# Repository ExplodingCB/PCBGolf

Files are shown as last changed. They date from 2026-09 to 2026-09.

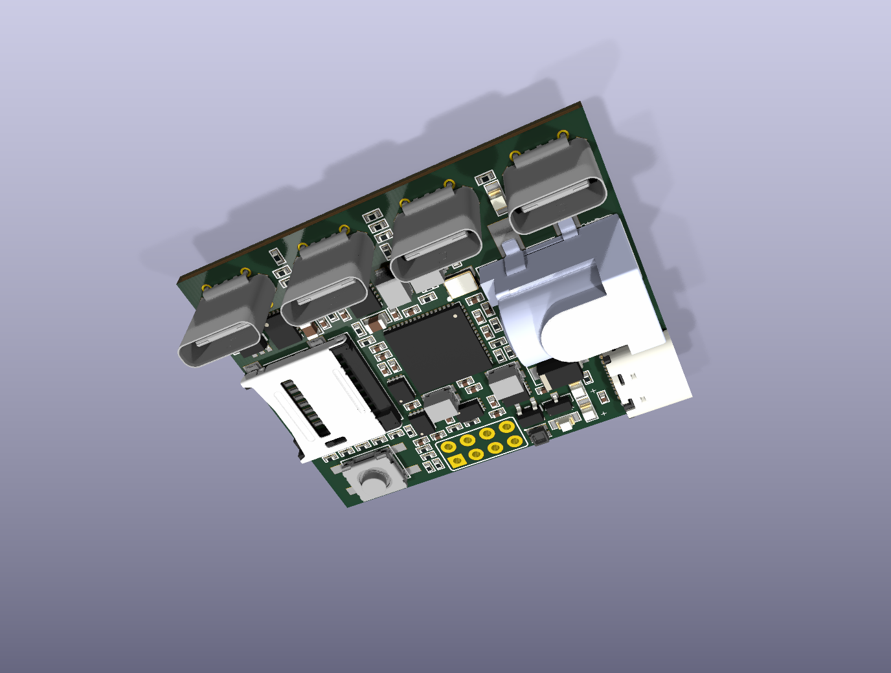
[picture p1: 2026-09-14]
reports/current-placement.png

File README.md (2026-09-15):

> **Engineering handoff — incomplete and not submitted.** Start with [HANDOFF.md](HANDOFF.md). The latest 45 × 37 mm, four-layer BGA100 checkpoint is in [work-in-progress/](work-in-progress/README.md), including an assembly STEP. It has **184 remaining pad-group connections and zero physical DRC errors**. Work stopped at the owner's request; all subagents and routing jobs are stopped. The root project is an earlier placement baseline.

<div align="center">
<h1>PCBGolf Challenge</h1>
<h3>How small can you make this PCBA?</h3>
<h3>
  <a href="https://comma.ai/leaderboard#pcbgolf_challenge">Leaderboard</a>
  <span> · </span>
  <a href="https://comma.ai/jobs">comma.ai/jobs</a>
  <span> · </span>
  <a href="https://discord.comma.ai">Discord</a>
  <span> · </span>
  <a href="https://x.com/comma_ai">X</a>
</h3>
</div>

## The Board

The schematic is loosely based on [our panda jungle v2](https://www.comma.ai/shop/panda-jungle), a development and debugging board for comma devices and pandas. This version includes:

* 12V DC input with onboard 5V and 3.3V supplies
* Four [OBD-C](https://github.com/commaai/hardware/blob/master/harness/OBD-C.sch.pdf) device ports with individually controlled power and current monitoring
* Four CAN transceivers and ignition simulation circuitry
* A USB hub and USB-C host connection
* An STM32H725 microcontroller and microSD card slot
* A push button and status LEDs

Explore in your browser with KiCanvas: [PCB layout](https://kicanvas.org/?github=https%3A%2F%2Fgithub.com%2Fcommaai%2FPCBGolf%2Fblob%2Fmaster%2Fpcbgolf.kicad_pcb).

Schematics: [Power](https://kicanvas.org/?github=https%3A%2F%2Fgithub.com%2Fcommaai%2FPCBGolf%2Fblob%2Fmaster%2Fpcbgolf.kicad_sch) · [Microcontroller](https://kicanvas.org/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) · [USB & microSD](https://kicanvas.org/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) · [CAN](https://kicanvas.org/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) · [OBD-C ports](https://kicanvas.org/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)

PCBgolf — A little board goes a long way. $1,000 prize.

## The Challenge

Your goal is to make the most compact, efficient board that retains the same interfaces and functionality as the original design. The lowest score wins.

<p align="center">
  <picture>
    <source media="(prefers-color-scheme: dark)" srcset="./assets/score-dark.svg">
    Score = PCBA bounding box volume (mm³) + 50 × number of vias + 5,000 × number of copper layers.
  </picture>
</p>

### Rules

* The bare PCB must be fully manufacturable by JLCPCB.
* It must be possible to actually assemble the PCBA.
* The assembled product must work and be usable.
* Mating connectors must remain mechanically and electrically compatible.

### Prize

Lowest score on the [leaderboard](https://comma.ai/leaderboard#pcbgolf_challenge) by **October 12, 2026** wins **$1,000 cash**.

## Submission

Submit a `.zip` file containing your finalized KiCad project and a STEP file of the final assembly [here](https://forms.gle/US88Hg7UR6bBuW3BA).
Competitive scores will be posted on the [leaderboard](https://comma.ai/leaderboard#pcbgolf_challenge) after review. Multiple submissions allowed.

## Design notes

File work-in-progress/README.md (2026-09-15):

# PCBGolf engineering checkpoint

Updated September 14, 2026. **Incomplete, not fabrication-ready, and not submitted.** Work stopped at the owner's request. Start with [../HANDOFF.md](../HANDOFF.md) for exact artifact provenance, remaining blockers, toolchain and proposed continuation plan. All subagents and routing jobs are stopped.

## Current design

- 45 × 37 mm outline, four copper layers, 1.6 mm PCB thickness, 239 components.
- STM32H725VGH6 in an 8 × 8 mm TFBGA100 package, with corresponding schematic and GPIO changes.
- Project-local schematic symbols, footprints and 3D models are included. Open `pcbgolf.kicad_pro` here; the repository-root project is an earlier placement baseline.
- This snapshot is the last completed `via400` routing result: 2,715 track segments and 484 through vias. `pcbgolf.merge.json` records the initial merge only.
- `assembly.step` contains the board and all 236 populated component models. All 239 component placements were compared and exactly match this latest PCB; only routing changed after the STEP export. Final fabrication artifacts should be exported again.

## Known blockers

- `net-groups.json` reports **184 missing connections between connected pad groups across 113 nets**.
- `drc.json` contains **zero physical error records and zero hole-spacing warnings**. Unconnected items and other warnings still require completion and review.
- `connectivity-parity.json` passes all five schematic sheets: 239 components, zero component or pin/net differences.
- `usb-reference-audit.json` verifies all 17 ground return vias connect to both original inner layers. One small reference-copper gap remains flagged among 223 USB segments.
- CAN bus routing is partly integrated; connector and transceiver branches still require connections. The older isolated trial is documented separately in `../reports/can-routing-trial.md`.
- Power distribution, current capacity, final manufacturing checks and firmware/hardware validation remain unfinished. Some vias require filled and capped via-in-pad processing.

## Preserved work

Engineering scripts and reports are in `../scripts/` and `../reports/`. Reports describe their named candidates. `routing-source.*` and `routing-handoff/via400*` preserve the exact source, DSN, SES, hash and log for the latest output. `small-via-trial.*` is a separate older 190-open experiment with 130 reduced signal vias; do not replace the latest main board with it. Other experiments and installed toolchains remain local and are excluded from Git. **No six-layer conversion was implemented.**

Firmware source changes and the local build driver are in `../firmware/pcbgolf/`. Bootstub and application compiled and linked locally; neither was hardware-tested. No flashable binaries are included in this checkpoint.

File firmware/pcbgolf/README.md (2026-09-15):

# Experimental PCBGolf firmware

Source checkpoint for STM32H725VGH6 BGA100. Bootstub and application compiled and linked locally; hardware behavior and the complete pin map still require review and bench testing. This is not qualified firmware.

The build uses commaai/panda revision `78cf69904c332c599a297fcc2a09c08d10d429d5` and commaai/opendbc revision `057aee25b5eee7530f0b95b5b508c8c3247b0cd7`. Place the panda checkout at `tools/panda-firmware` and opendbc at `tools/panda-firmware/opendbc-src` relative to the repository root.

Apply `panda-changes.patch` inside the panda checkout, and copy `pcbgolf_bga100.h` to its `board/jungle/boards/` directory. The patch selects the PCBGolf board and overrides the historical TFBGA100 supply heuristic for the H725 SMPS and externally supplied USB rail.

`build.py` records the expected local Arm GNU 12.3.Rel1 Windows toolchain path and builds both images with `PCBGOLF_BGA100`. Generated outputs stay in the ignored `build/` directory. See `../../reports/firmware-build.json` for the saved compile result; it does not establish hardware correctness.

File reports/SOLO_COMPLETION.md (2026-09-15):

# Solo completion status — September 14, 2026

The owner requested a WIP push followed by continued work without subagents. All three agents are stopped. Continue toward a valid submission; do not restart size optimization or claim the active challenge goal is complete.

> **Superseded at the September 14, 2026 handoff.** The owner stopped work and requested a push for another engineer. Read `../HANDOFF.md`. Latest pushed board: 184 missing connections, zero physical DRC errors. No router or subagent is running. The following entries are chronological notes, not current instructions.

## Earlier checked checkpoint

`candidates/completion/finish.kicad_pcb`, copied into `work-in-progress/pcbgolf.kicad_pcb`: 45 × 37 mm, four layers, 239 components, 2,297 track segments and 417 vias. Native DRC: 220 opens, zero physical errors, zero hole-spacing warnings. No valid score or submission yet.

The original merged snapshot had 519 missing pad-group connections. Three USB ground-return vias had been reassigned to connector VBUS during zone integration. They were restored and set to free vias to preserve explicit net assignments. New ground fanout, local SMPS links, a front 3.3 V pour, and partial CAN routing are included.

The crystal is now at (3.6,15.35), C14 at (3.6,17.4), C17 at (1.0,16.3), and C19 at (4.05,24.3). The four clock links route on the bottom, with lengths 7.408/2.851 and 3.469/2.097 mm in the earlier validated clock result; the exact C17 move subsequently updated its short branch. `complete_clock.py` reproduces the layout and `repair_route_import.py` restores the checked clock geometry while removing only newly imported copper that violates native rules.

Five-sheet parity passed before these placement-only changes. Final parity must be rerun against the submission artifact. Earlier STEP bounds were 45 × 37 × 14.23 mm with no component AABB collisions; the WIP STEP is freshly exported after the clock move, but final geometry checks remain required.

USB's 17 return vias connect to both inner ground layers. Reference copper passed after removing 34 intruding CAN segments and adding inner track keepouts. One small reference gap reappeared after subsequent general routing; rerun the reference audit against the final board. `prepare_router.py` explicitly exports these keepouts because KiCad omitted track-only rule areas from its DSN.

## Router progress and next action

The current job uses `candidates/completion/flexible-bus.kicad_pcb`, with long CAN bus copper unlocked but the 32 checked connector escape vias preserved. Its input is `pofv.dsn`, its output will be `pofv.ses`, and its log is `pofv-router.log`. Native import must use the matching `pofv.preflight.json` source hash. The job is bounded to five minutes.

Filled/capped SMD vias require both `(attach on)` in via padstacks **and** `(control (via_at_smd on))` in the DSN structure. The earlier `finish` and `flexible` runs lacked the latter control; `pofv` enables both. Native DRC and a full filled/capped via map remain mandatory.

The local router JAR has only its existing normalization-loop limit reduced from 2,000 to 64, preventing long cleanup oscillations. `bound_router_cleanup.py` reproduces this isolated copy and records its hash; the official JAR is retained. No clearance or routing correctness checks are removed. Commands also use a five-minute job timeout, disabled optimizer, a 0.10 mm neck-width floor, 0.20 mm hole clearance and 0.30 mm copper-edge clearance.

## Remaining acceptance work

Complete all signals and power pad groups, repair any imported physical errors, recheck USB geometry/reference copper and clock preservation, verify power distribution and current capacity, final five-sheet parity, complete assembly and mating checks, final score and self-contained ZIP, then the official submission form. The form requires Google authentication; no submission has been made.

Experimental firmware compiled and linked. The new `audit_firmware_pinmap.py` checks 44 GPIO/ADC/CAN allocations against the schematic allocation and official ST pin data; all pass. `firmware/pcbgolf/pinmap.json` holds the results. Hardware operation and unimplemented peripheral behavior remain untested.

## Later solo routing handoff (21:30 local)
The 220-open WIP was pushed as commit 259a4a1. True via-at-SMD mode produced candidates/completion/pofv.kicad_pcb: 207 native opens, 2454 tracks, 447 vias, zero physical errors. connect_short_nets.py then connected 6 of 43 attempted local pairs; candidates/completion/short-links.kicad_pcb is the new router source (native preflight passes). Current running job: long-run.dsn -> long-run.ses, source hash in long-run.preflight.json, log long-router.log, ten passes and a twenty-minute timeout, started about21:27:40. Exec session5241. Do not run another concurrent router or reactivate agents. Import its SES into the matching short-links source, then run native DRC and uncapped connectivity.
connect_power_vias.py is written but NOT YET RUN. Apply it to the best completed general-routing result. It proposes legal0.4/0.2mm filled/capped vias on disconnected power/GND pad groups, refills, and prunes additions whose removal does not worsen pad-group count. Native DRC, final power capacity and USB reference review remain mandatory. The final four-layer board is still incomplete; do not claim ready or submit.

## Dense-routing constraints found (21:42 local)
The long job completed two passes with the same191 internal unrouted count (no improvement on pass2); it is due to time out around21:47:40. Do not repeat unchanged settings. DSN Default class had a use_via restriction to0.45/0.20mm even though the0.40/0.20mm padstack already existed. prepare_router.py now selects the0.40/0.20mm stack when filled-via mode is enabled; that change is NOT in the currently running long-run.dsn. Verified generated DSN has both control/via_at_smd on and class/use_via400. For the next completion run, increase --router.scoring.unrouted_net_penalty=100000000 (default5000000) so false router-only DRC counts cannot outweigh completing connections. Do not disable native checks or change manufacturing rules. The router internal score is higher-is-better and includes a1000000 penalty for each router DRC record; native PCB currently has no physical errors despite hundreds of router-only reports.
If a six-layer power-distribution change eventually becomes necessary, official JLCPCB stackup page https://jlcpcb.com/impedance lists JLC06161H-3313 with the same0.09940mm outer prepreg as current4L;0.55mm cores,0.1088mm central prepreg,0.0152mm inner copper. This is only research, no6L conversion has been applied. First finish the0.4mm-via path and power connections on4L.

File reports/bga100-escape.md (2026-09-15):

# BGA100 through-via escape experiment

The recommended isolated candidate is **`candidates/bga100-power-escape/pcbgolf.kicad_pcb`**. It uses the new power placement and reaches every connected MCU ball with **32 vias**, while preserving all 18 no-connects. Both the original `bga100-base` and the source `bga100-power-base` are unchanged. This is complete MCU fanout access, not completed end-to-end board routing.

## Measured result

| Item | Count |
|---|---:|
| Actual MCU balls | 100 |
| Connected balls / retained no-connects | 82 / 18 |
| First/second-row or critical supply access on B.Cu, without vias | 47 |
| Balls with through-via dogbones | 35 |
| Added through vias | **32** |
| Shared same-net vias | 3 |
| Total balls with access | **82 / 82** |
| Balls still without access | **0** |
| Added track segments | 102 |

Native KiCad DRC reports **zero physical violations**, including warning-level hole-spacing checks, with no DRC exclusions or rule changes. The 27 dangling-via and 47 dangling-track warnings identify intentionally unfinished signal routes. Five GND vias connect all six ground balls into filled In1 GND copper, checked using native filled-zone geometry. Five-sheet logical parity passes with zero component or pin-net differences across all 239 parts. Unconnected records are capped at 499, so this number is a lower bound. Remaining silk/text warnings and two existing footprint-library mismatches need final cleanup.

Every via is a **0.45 mm copper / 0.20 mm through drill**, reached by a **0.12 mm B.Cu track** at ±0.4 mm x/y offsets from a ball. Candidates screen copper and drills on every layer, including opposite-side SMD pads, before native DRC. No via-in-pad, microvia, blind via or clearance waiver is assumed. The 0.45 mm component-PTH-to-component-PTH and 0.20 mm generic drilled-hole separation rules remain in the copied project.

## Placement and via reduction

| Experiment | MCU center | Accessible balls | Vias | Physical DRC |
|---|---|---:|---:|---|
| Original pose, one direct row | 15.6, 19.9 | 66/82 | 36 | Passed |
| Shifted pose, one direct row | 10.5, 19.9 | 82/82 | 50 | Passed |
| Shifted pose, two direct rows | 10.5, 19.9 | 82/82 | 32 | Passed |
| New power placement, two direct rows | 10.5, 19.9 | 82/82 | **32** | **Passed** |

At the original pose, opposite-side U7, C35, U4, C33 and C30 blocked the dogbone grid. Moving the MCU left resolved all blocked sites without moving the hub or transceiver. X=9.5 and x=11.5 at y=19.9 also passed complete one-row escapes; x=10.5 was chosen for the power placement. The second direct row removed **18 vias**, saving **900 challenge score points** relative to the first complete 50-via fanout, before any later routing changes.

Final MCU pose is **x=10.5, y=19.9 mm, B.Cu, 0°**. Balls occupy x=6.9–14.1 and y=16.3–23.5 mm. The original 10 × 10 mm BGA courtyard is retained. Bottom direct-access stubs reach x=6.1/14.9 and y=15.5/24.3; subsequent placement must include trace copper and clearance beyond these centerlines.

Shared vias are C1/D1 GND at (6.5,21.5), D6/E5 +3V3 at (10.5,20.7), and G6/F7 VDDLDO at (11.3,19.1). C2/VBAT exits through the gap above C1, preserving the shared ground-via cell beside the switching escape.

## Reserved MCU supply access

- D2/VLXSMPS: (7.7,21.1) → (7.3,20.7) → (6.1,20.7), B.Cu.
- E2/VFBSMPS: (7.7,20.3) → (7.3,19.9) → (6.1,19.9), B.Cu.
- E1/VDDSMPS reaches (6.1,20.3) on B.Cu.

These keep switching and feedback access direct. The new power placement brings L4's switching pad to (5.07,20.7); its bulk/bypass parts are nearby. Actual supply interconnects remain for the power-routing stage. The 0.12 mm stubs demonstrate geometric access and are not final current/inductance sizing. In2 stays +12V; MCU +3V3, VDDLDO and VDDA require correctly named local supply copper and decoupling. No fanout is connected to the wrong plane. Supply requirements are in `reports/mcu-bga100-supply-check.md`. USB fanout access has not been certified for differential impedance or skew.

## Reproduce or refresh

```powershell
tools/kicad/bin/python.exe scripts/escape_bga100.py --source candidates/bga100-power-base --output candidates/bga100-power-escape --direct-rings 2
```

For a copy that already contains a prior escape and its matching `escape-report.json`, remove only the listed old escape UUIDs in another output copy before rebuilding:

```powershell
tools/kicad/bin/python.exe scripts/escape_bga100.py --source candidates/your-placement-copy --output candidates/your-refreshed-escape --refresh-known-escape --direct-rings 2
```

The refreshed input must contain only the known escape tracks/vias; other newly routed copper is rejected until that use case is explicitly supported. This prevents silently omitting existing routing obstacles. The script saves its report, native DRC JSON and merged connectivity report beside its output board.

## Assembly spacing

The BGA courtyard was kept at its official size. KiCad specifies a 1.0 mm BGA courtyard allowance. JLC's current recommended minimum component spacing is 1.0 mm between a BGA and chip passives, and 1.5 mm to QFN/QFP. Reducing the courtyard does not establish assembly-process acceptance. The native copper/hole checks above are separate from the final assembly and mechanical review. [KiCad KLC F5.3](https://klc.kicad.org/footprint/f5/f5.3.html), [JLC SMD spacing](https://jlcpcb.com/help/article/minimum-spacing-for-smd-components)

## USB integration reservation

`candidates/bga100-power-escape-usb-reserved` preserves the generic fanout reference above and replaces only its three STM_D_P/N access tracks. It adds the USB routing agent's two 0.40/0.20 mm vias: P at U3.D9 (13.3,21.1), and N at (13.7,20.7) with a 0.11 mm B.Cu diagonal from D10 (14.1,21.1). This snapshot has **34 total vias and 100 track segments**, zero physical DRC violations and passing five-sheet parity. Its `usb-reservation.json` records every removed/added UUID for integration.

The P via is **via-in-pad and requires filled, copper-capped POFV**. The reserved USB path is not yet a completed differential route; the USB agent will retain these vias and add its matched continuation. Do not duplicate them when combining candidates. The original 32-via generic fanout remains unchanged for evidence.

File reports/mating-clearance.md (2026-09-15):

# Mating connector clearance

## Finding

The first 45×37 mm layout's OBD-C socket row had 11.3–11.7 mm spacing along the plug's wide axis. **This does not accommodate every compliant full-featured USB-C plug.** USB-IF Table B-1 specifies maximum overmold width **12.35 mm** and height **6.5 mm**. [Official compliance document, printed page49](https://www.usb.org/sites/default/files/USB%20Type-C_Compliance%20Document_Rev_2_1b_June_2021.pdf).

Comma describes OBD-C as a fully connected USB-C 3.1 Gen2 or 3.2 Gen2 cable. Its public hardware documentation does not provide an exact proprietary overmold drawing. [Comma hardware harness documentation](https://github.com/commaai/hardware/blob/master/harness/README.md).

## Corrected candidate

`reports/placement-45x37-mating.json` rotates all four OBD-C sockets by90° and places them at X=3.25,10.75,18.25,25.75 mm, Y=4.75 mm. Their **narrow-axis pitch is7.5 mm**. This provides1.0 mm between maximum-width USB-IF compliant overmolds in that direction.

The mechanical check deliberately enlarges the USB-IF cross section to **12.5×7.0 mm**, giving **0.5 mm interplug separation**. The rightmost envelope ends atX=29.25 mm; the actual tall barrel-jack model begins atX=29.6 mm, giving0.35 mm clearance. The cable bodies may overhang short components because the plug overmolds begin above the vertical USB sockets, roughly8.8 mm above the board. The audit starts them at8.6 mm to include an extra0.2 mm vertically.

J4 moves to the clear upper-right corner at(38,4), and the bottom MCU shifts toY=20.7 mm so all connector drill envelopes clear it. The board remains45×37 mm. The PNG shows elevated cable envelopes as dashed yellow rectangles. They are usability checks and are excluded from PCBA volume scoring.

## Scope

These calculations check simultaneous insertion geometry using conservative straight-plug envelopes and nominal component models. They do not establish insertion force, latch retention, cable bend space, or compatibility with unusually oversized/right-angle custom cable housings. A representative physical mating test remains part of final validation. The optional DNP J4 header requires its own mating-body model if populated.

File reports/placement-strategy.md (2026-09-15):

# Compact placement strategy and measured candidates

## Current recommendation

Use `reports/placement-45x42-courtyards.json` as the next native KiCad placement. It places **239 footprints on a 45 × 42 mm PCB** and preserves the actual source and corrected-library assembly courtyards. The plan includes every remaining electrically required reference after the separately verified removal of four unconnected mounting holes and redundant R5/R6 divider resistors. JSON contains native footprint origins, rotations, and sides, plus conservative occupied bounds.

This is a placement candidate, not a completed submission. Routing, current capacity, USB impedance, electrical checks, connector insertion clearance, and final assembly checks remain required.

## Measured bounds and scoring

The native STEP exports of `compact-v1-4l` and `compact-v2-4l` measure **45 × 42 × 15.005 mm**, giving **28,359.45 mm³** of assembly volume. These measurements come from the actual exported assembly using OpenCascade, not a sum of nominal package heights. J1 sets the top height; the bottom CAN chokes set the lower extent. The exported assemblies contain 236 populated component models plus the PCB; C6, C10, and J4 are DNP in the corrected project.

At this measured size:

- Two-layer score before vias: 38,359.45.
- Four-layer score before vias: 48,359.45.
- Every 100 vias adds 5,000.
- Shrinking board width by 1 mm at fixed height saves about 630 score.
- Shrinking board height by 1 mm saves about 675 score.
- Lowering the assembly by 1 mm saves 1,890 score.
- A two-layer design may use **200 additional vias** before it loses its 10,000-point copper-layer advantage, assuming the same physical volume.

The original pad/body rectangle sum was 2,229.61 mm². Its optimistic two-sided area floor was 1,114.81 mm², before routing, courtyards, connector insertion, thermal clearance, and packing waste. Correcting oversized SOIC-8 footprints to the actual SOT-553 part and removing the approved unnecessary items lowers physical occupied area, but J1's corrected 17 mm pad span increases it. V3's actual courtyard/body envelope sum is 2,432.47 mm², about 64% of the available two-sided 3,780 mm² surface.

## Fixed interface arrangement

Coordinates are millimetres. Rotations follow KiCad; bottom footprints are flipped top-to-bottom before applying the listed angle.

| Reference | Side | Footprint origin | Angle | Access |
|---|---|---:|---:|---|
| U3 | Top | (13.0, 22.5) | 180° | Rotation puts oscillator pins on the free right side and SD pins toward the left |
| J1 | Top | (39.5, 17.5) | 180° | Barrel opening faces the right board edge |
| J2 | Bottom | (1.31074, 15.125) | 90° | microSD opening faces the left edge |
| J3 | Top | (37.0, 33.15) | 0° | Host USB-C opening reaches the bottom edge |
| J4 | Top | (7.0, 38.5) | 0° | Original 2×4 CAN pad interface retained, DNP |
| J5–J8 | Top | X = 5.0, 16.7, 28.3, 40.0; Y = 4.0 | 0° | Vertical OBD-C insertion from above |
| SW1 | Top | (22.5, 38.5) | 0° | Finger access from above |
| U4 | Bottom | (22.0, 20.0) | 0° | Consider 270° in the next route-focused revision |

The OBD-C sockets are spaced 11.3–11.7 mm apart. Their bare sockets do not intersect. The **actual required cable overmold width** still needs verification; a plug wider than the socket spacing can invalidate this arrangement. Connector cable bodies are not included in the bare PCBA STEP score and cannot be ignored when checking usability.

## Placement constraints and verification

- Native KiCad STEP positions match the planner's mirrored-Y bottom-side transform, including the asymmetric microSD socket. The convention was checked on exported models rather than assumed.
- V2 has no pair of component 3D bounding boxes intersecting by more than 0.001 mm. Separated boxes prove separated solid models. PCB/lead insertion intersections are intentionally excluded from this test.
- Actual SOT-553 model size is 1.6 × 1.6 × 0.63 mm; the original pad-only estimate missed 0.15 mm of body extent per Y side. V3 preserves the full 2.36 × 2.20 mm library courtyard.
- Actual U3 courtyard is 23.3 × 23.3 mm, and the source-board 0402 courtyards are 1.946 × 0.966 mm. These are larger than the bare pad rectangles and were the cause of V2's courtyard errors. V3 incorporates them directly, with a further 0.05 mm gap. No courtyard was artificially reduced.
- J1 requires the corrected `PJ-002AH-SMT-TR` footprint. Its copper bounding box is local X [-1.25, 7.25], Y [-8.5, 8.5], and its full courtyard is [-5.3, -8.75, 10.2, 8.75]. The first bootstrap placement used the supplied incorrect footprint; V2 and V3 reserve the corrected physical pad span.
- The planner reserves through-hole and locating-hole obstacles on the opposite side as well as the component's own side.
- MCU crystal and bypass capacitors stay on the MCU side. Hub crystal and bypass capacitors stay on the hub side. Both switching regulators, their inductors, bootstrap/input/output capacitors, and feedback parts stay on the bottom side together. Placement priorities use actual relevant IC pin locations when available.

## USB routing priorities

`reports/usb-route-corridors.json` records the native pad endpoint coordinates for all six USB differential pairs. Route these before general signals and preserve pair spacing, a continuous reference plane, and equivalent via transitions. An unrestricted autorouter trial only establishes reachability; it does not establish USB signal integrity.

With U4 at (22,20), rotating it from 0° to **270°** reduces the sum of 12 USB-net Manhattan endpoint distances from **331.9 to 288.5 mm**, and turns its four OBD-C pair groups toward the top port row. The hub crystal and local bypass capacitors must be repacked if this change is adopted. For the present 0° orientation, route the four OBD-C pairs around the left/top hub side, the host pair toward the lower-right connector, and the MCU pair toward the lower-left MCU edge. Avoid crossing the microSD socket's routing escape with all four port pairs on the same layer.

## Files

- `scripts/placement_analysis.py`: source pad/model geometry inventory.
- `scripts/compact_placement.py`: first net-attracted bootstrap placement.
- `scripts/refined_placement.py`: same-side critical loops and enlarged J1.
- `scripts/courtyard_placement.py`: current courtyard-preserving placement.
- `scripts/render_placement.py`: PNG review renderer.
- `scripts/inspect_assembly.py`: actual STEP component names and bounds.
- `scripts/audit_assembly.py`: 3D separation and measured volume report.
- `scripts/usb_corridors.py`: exact USB endpoint coordinates and hub rotation comparison.
- `reports/compact-v2-4l-mechanical-audit.json`: native V2 model separation and dimensions.

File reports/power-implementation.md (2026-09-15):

# Power implementation and handoff

## Concrete candidate

Use `candidates/power-base/power-critical.kicad_pcb`, with its matching `.kicad_pro` and `.kicad_dru`. The placement-only base is `candidates/power-base/pcbgolf.kicad_pcb`; `reports/placement-power-clusters.json` records all239 positions. This is an isolated45×37×1.6mm four-layer candidate. Root and the USB agent's active board were not overwritten.

The board contains58 power/thermal vias and143 track segments. All201 copper items are locked. Sixteen vias are0.20mm holes/0.40mm copper in eFuse exposed pads and require epoxy-filled, copper-capped POFV. Their closest component-hole edge gap is2.019mm, exceeding the conservative0.45mm requirement. The exact UUID/coordinate map is in `candidates/power-base/power-audit.json`. Paid four-layer POFV is documented in `reports/pofv-four-layer.md`.

Native KiCad10.0.6 DRC reports zero error-severity violations,285 warnings, and499 reported unconnected items. The unconnected list reaches the report limit; this is an incomplete board. Combined five-sheet logical parity passes for all239 parts with zero component or pin/net differences. Reports: `critical-drc.json`, `connectivity.json` in the candidate directory.

## Electrically connected power paths

The audit unions actual filled polygons with tracks/pads on every layer, including polygon holes, then connects layers only through actual vias/PTHs. It confirms:

- Both J1 power lands, D1 and every Q1 drain pad share one copper group.
- Q1 source pads, all20 eFuse VIN pads, U2 VIN, C3 and C5 share the+12V group through In2.Cu.
- Each eFuse's five output pads connect to all four corresponding connector VBUS contacts. The four output nets remain separate. LED-series resistors R74–R77 still need their low-current branches.
- U1 SW, L1 input and C4 switch side connect together. U3 VLXSMPS→L4→C25 has a2.681mm,0.30mm main route and1.286mm,0.20mm snubber branch.

Local output pours occupy both outer layers and leave the USB center/right exit reservations. The supply transition banks use parallel vias; short pin escapes are0.20–0.80mm wide. These facts establish electrical continuity, not an ampacity rating. Filled-copper neck widths, via current sharing and return-path temperature still need calculation and hardware validation after USB/general routing.

## Limits that must remain explicit

J1 is a5A total input jack. Each TPS25944A has a nominal3.18A trip setting with28kΩ ILIM; simultaneous channel maxima exceed the jack rating. AP62300 is a3A IC, but both selected3.3µH inductors have1.8A saturation/2A thermal ratings. Do not rate either assembled rail3A from the IC name alone. The existing+3V3 rail is cascaded from+5V, so combined regulator loading matters.

The preliminary1oz/10°C screen uses3.5mm drawn input trunk width and5.5mm channel trunk width for the TI twice-full-load copper recommendation. The current pours have not demonstrated these widths at every bottleneck. No thermal or load rating is asserted.

## Required next changes

1. Move eFuse input10µF/100nF capacitors near each VIN bank. C50–C52 and several small bypasses are remote. Connector shield holes and the LQFP courtyard block the convenient lower row; the BGA100 branch frees that area. Proposed bypass repack script currently refuses this collision and has not changed the saved placement.
2. Repack U1/U2 dividers and bootstrap capacitors beside the respective pins. R3/R4 are13.65/10.31mm from U1 FB; R9/R10 are6.06/8.40mm from U2 FB. These require placement correction. The5.75mm bootstrap paths are provisional and should shorten with the move. U2SW→L2 and U1VIN→C1 remain open.
3. Complete MCU direct-SMPS input/output loop. L4 output→VFBSMPS/VCAP/VDDLDO and bulk C21/C15 remain unconnected; the bulk caps are26.14/28.04mm away and must move. U3VDDSMPS→C23 also needs a short path. L3 is the analog ferrite, not the SMPS inductor.
4. Add eFuse/MCU/regulator ground returns and general GND fanout with the parent's ground script after final placement. Exposed-pad thermal vias are already present; avoid duplicates. No ground copper ampacity claim is made.
5. Merge USB geometry, refill all zones, repeat actual connected-group and copper-neck checks, native DRC and locked-copper preservation after DSN routing. Lock flags alone do not prove an autorouter preserved copper.

## Reproduction

`route_power.py` creates local pours and parallel transitions from a separate input board; `route_critical_power.py` adds checked local switching paths. `audit_power_copper.py` audits actual filled geometry. All operate on explicitly named files. `place_power_clusters.py` is an earlier setup script and should not be rerun on the finished candidate, because it resets placement. The latest placement JSON is the integration source of truth.

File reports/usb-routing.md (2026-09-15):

# Critical USB routing handoff

## Frozen result

`candidates/compact-v6-usb/pcbgolf.kicad_pcb` contains all six USB2 differential pairs on the 45 × 37 mm BGA100 placement. Its SHA-256 is `26e415a34c48df2f99a4949cb7b7c267e3b41954c95b710ab42058513fc0015e`.

Source: `candidates/bga100-power-escape-usb-reserved/pcbgolf.kicad_pcb`, SHA-256 `5782dc9af71da970fa03c2ad8e56940334bf2bed77e5315e483b365e95a40fde`. The prepared candidate preserves all non-USB BGA escape copper. It regenerates the two reserved STM USB vias at their exact original positions; it contains no duplicate STM vias.

Merge `reports/usb-paired-routes.json`: **223 locked USB track segments, 40 signal vias, 17 ground return vias, and 10 In2 GND reference patches**. Net names and native layer IDs are explicit. The full file/hash/fabrication inventory is `reports/usb-critical-manifest.json`. Placement remains that of the frozen source.

## Validation

- Native KiCad custom manufacturing DRC: **zero error-severity physical violations and zero USB unconnected items** after refilling zones. The rest of the board remains unfinished: 499 unconnected items and 604 non-error DRC warnings remain in this isolated candidate.
- Five-sheet schematic parity: **239 components, zero component or pin-net differences**, `reports/usb-connectivity-parity.json`.
- Every USB track and every newly added signal/return via is locked. Non-octilinear segments must retain their exact coordinates through DSN export/import.
- Every signal path has equal P/N layer-transition counts, including both reversible contact groups.

| Pair | A orientation mismatch | B orientation mismatch | P/N vias on each path |
|---|---:|---:|---|
| Host USB | 1.150 mm | 1.150 mm | 2 / 2 in either orientation |
| CH1 | 0.610 mm | 0.960 mm | A: 2 / 2; B: 4 / 4 |
| CH2 | 0.440 mm | 1.130 mm | A: 2 / 2; B: 4 / 4 |
| CH3 | 0.597 mm | 0.973 mm | A: 2 / 2; B: 4 / 4 |
| CH4 | 0.538 mm | 1.032 mm | A: 2 / 2; B: 4 / 4 |
| STM MCU | 0.569 mm | — | 1 / 1 |

Lengths are native connectivity graph centerline measurements, excluding travel inside pads. Full-thickness F↔B barrel estimates cancel between P/N because transitions are balanced. This is a geometry audit, not an electromagnetic simulation or USB compliance test. Detailed paths, endpoint resolution and uncoupled-length estimates are in `reports/usb-native-path-analysis.json`. The 1.25 mm mismatch target comes from [Microchip AN26.2](https://ww1.microchip.com/downloads/en/Appnotes/AN26.2-Application-Note-DS00001876C.pdf).

## Stackup and fabrication

Use **JLC04161H-3313, 1.6 mm, four copper layers**. Long paired traces use **0.11 mm width / 0.10 mm copper-edge gap**. The official JLC coated differential-microstrip calculator returned **90.158064 Ω** for this geometry, using 0.0994 mm outer-to-adjacent-plane dielectric and Er 4.1. Evidence: `reports/jlc-usb-width011-gap010.json`, [JLC impedance calculator](https://jlcpcb.com/impedance). Short connector fanouts and layer transitions are explicitly uncoupled and need final SI review.

All new through vias use **0.40 mm copper diameter / 0.20 mm drill**. The manifest explicitly flags **14 vias requiring POFV: resin fill, planarization and copper cap** where a drill intersects a component pad. That includes 13 USB signal vias and one ground return via. Apply these requirements in the fabrication output; a JSON flag alone does not instruct the manufacturer. Existing BGA and power via-in-pad requirements remain additional to this inventory.

## Actual reference copper

Top USB references the In1 GND plane. Short bottom branches reference **priority-100 In2 GND patches**, agreed with the power agent so VDDLDO priority-40 regions cannot replace their reference copper.

`scripts/usb_zone_geometry.py` exports the **actual filled polygons including holes**, and uses native connectivity to check each return via on In1 and In2. `scripts/usb_reference_audit.py` checks a **±0.25 mm corridor around every one of the 223 conductor segments** against the filled reference copper. All segments pass outside explicitly enumerated signal/plated-hole/NPTH antipads and the zone's 0.15 mm minimum-copper-neck removals. Numeric tolerances are recorded: 0.003 mm fill comparison and 0.012 mm antipad polygon allowance. The short 0.6 mm balancing bridges have merged endpoint antipad openings; they are launch exceptions rather than continuously plane-backed lines.

All **17** ground return vias have native direct connectivity on **both In1 and In2**. Every signal via is within **1.4731 mm** of one of these returns. The 1.5 mm placement target is a design choice, not a cited standards limit. Full results, exception coordinates and native return checks are in `reports/usb-reference-audit.json` and `reports/usb-filled-zones.json`.

## Integration requirements

1. Merge the exact USB JSON onto the latest power candidate, deduplicating the two already reserved STM vias and any coincident ground vias.
2. Preserve all locked track coordinates, vias and priority-100 reference outlines during routing. Reserve their inner-layer filled copper against generic signal routing and power regions.
3. Refill zones and rerun native manufacturing DRC, all-sheet parity, USB path analysis and the filled-reference audit **on the final integrated board**. Added vias and inner-layer tracks can interrupt an otherwise valid reference even when ordinary copper clearance passes.
4. Recheck actual filled power connectivity after the GND patches are merged. This isolated USB validation does not prove regulator, CAN or whole-board completion.

Reproduction order: prepare the frozen source with `route_usb_pairs.py --prepare --preserve-existing`; export native geometry with `usb_geometry.py`; run `usb_route_plan.py`, `usb_reference_planes.py`, and `finalize_usb_manifest.py`; apply the plan with `route_usb_pairs.py --plan`; refill native DRC; rerun connectivity/path/reference audits and refresh the manifest hashes. Each script owns only the isolated USB candidate or USB reports.

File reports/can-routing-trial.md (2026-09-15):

# Shared connector CAN bus routing trial

The frozen `candidates/canbus-vip-inner/pcbgolf.kicad_pcb` connects every CAN bus
between all four device ports and J4. It is an isolated routing experiment on
the earlier power placement, not the final integrated board.

## Verified result

- All 32 requested connector-to-connector links routed across eight nets:
  CAN0_H/L through CAN3_H/L.
- Native KiCad `GetConnectedItems` confirms J4/J5/J6/J7/J8 belong to one copper
  group on each of the eight nets. Chokes, termination and sensing branches
  still need their routes.
- Native all-track DRC has zero physical errors and no hole-spacing warnings.
- Connector fanout uses 32 vias, of which 28 are in pads and require filled,
  copper-capped fabrication. Bus continuation adds 15 vias. All use 0.45 mm
  copper and 0.20 mm drills; the local fabrication floor was not relaxed.
- Routing uses F.Cu, B.Cu and In2.Cu on the existing four-layer board. In1 stays
  the ground reference. In2 signals cut the +12V fill; final power continuity
  and copper-neck capacity must be rechecked after integration.

The two-outer-layer control trial reached only 15 of 32 links on this placement.
The lower-side eFuses and other parts block several connector bus corridors.
Moving the eFuses below the connector row is a separate optimization to examine
after the integrated four-layer candidate works.

## Reproduce

`escape_can_ports.py` runs with native KiCad Python and supports an explicit
`--allow-filled-via-in-pad` mode. Its adjacent `.escape.json` maps every added
via UUID to its contact and required fill/cap process.

`route_can_bus.py` runs with the workspace venv. Pass the escaped board and
`--fanout` report; `--inner-signal` enables the existing In2 layer for signals.
The script uses a 0.05 mm grid, explicit copper/drill obstacles and octilinear
tracks. Existing copper is retained, and the output is a separate board.

`audit_net_connectivity.py` uses native connected-item groups without KiCad's
DRC reporting cap. It reproduced the earlier v8 result of exactly 199 missing
pad-group connections, independently agreeing with its uncapped DRC report.
This count excludes orphan copper and all manufacturing/functionality checks.

Evidence resides beside the frozen candidate: `can-plan.json`, `drc.json` and
`native-net-groups.json`. The source snapshot hash is recorded in the plan.
The input's old MCU/power placement means the routes must be regenerated or
rechecked against the final BGA, power and USB copper before use.

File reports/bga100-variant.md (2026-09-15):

# Isolated STM32H725VGH6 variant

`candidates/bga100-base` contains the five-sheet project, board, local symbol/footprint libraries and STEP models. It changes U3 to an 8 × 8 mm TFBGA100 on 0.8 mm pitch. It remains an unrouted engineering candidate with firmware work outstanding.

## Validation completed

- All **239 components** retained; all **191 original connected PCB net names** retained.
- **100 distinct package balls:** 82 connected, 18 deliberately no-connect.
- Exact merged five-sheet schematic-to-board parity **passed**, with zero component differences and zero pin-net differences. Fifteen automatically generated net-name differences are electrically equivalent; the comparison checks actual peer connections.
- All 100 symbol pin numbers and normalized function names match [ST's official STM32H725VGHx pin XML](https://github.com/STMicroelectronics/STM32_open_pin_data/blob/master/mcu/STM32H725VGHx.xml). The ten moved GPIOs have their **names and numbers** changed in the symbol.
- Native KiCad 10 DRC under the copied JLC four-layer custom rules found **zero error-severity nonrouting violations**. It reported 250 warnings: 247 silk/text, two existing local footprint-library mismatches (J3/D1), and one isolated +12V plane region. It reported 499 unconnected records, which is KiCad's per-type cap and therefore a lower bound.
- Root project file hashes were unchanged during preparation. The 169-ball experiment and active routing candidates were not modified.

Evidence: `reports/bga100-connectivity.json`, `reports/bga100-native-drc.json`, and `candidates/bga100-base/bga100-status.json`. The board hash in the status and parity reports identifies the tested copy.

## Mapping policy

Connected signals claim their required target balls first. Unused original GPIOs are assigned only after these claims; this prevents an old no-connect such as PE5 from stealing its newly assigned BTN signal. Then remaining target no-connects retain matching functions. The smaller package drops redundant source supply terminals; every actual target supply ball is connected. No original connected signal net is deleted.

| Original GPIO | New GPIO / ball | Preserved net |
|---|---|---|
| PF7 | PA2 / H3 | Net-(U3-PF7) |
| PF8 | PA3 / G5 | Net-(U3-PF8) |
| PF9 | PA7 / K3 | Net-(U3-PF9) |
| PF10 | PC5 / J4 | Net-(U3-PF10) |
| PF11 | PB0 / K4 | CH3_IMON |
| PE15 | PE5 / A2 | BTN |
| PD12 | PE6 / A1 | CH3_SBU1_IGN |
| PD13 | PE7 / H5 | CH3_SBU2_RELAY |
| PG9 | PD13 / H10 | CAN2_TX |
| PG10 | PD12 / H9 | CAN2_RX |

Required alternate functions and ADC channels are recorded in `reports/mcu-bga100-feasibility.json`. Existing firmware is not binary compatible: pin definitions, ADC selection/channels, timing/DMA and startup supply configuration need implementation and build verification.

## Package and assembly geometry

The official [KiCad footprint](https://gitlab.com/kicad/libraries/kicad-footprints/-/blob/master/Package_BGA.pretty/TFBGA-100_8x8mm_Layout10x10_P0.8mm.kicad_mod) uses 0.400 mm copper pads, 0.035 mm radial solder-mask expansion and 0.8 mm pitch. These agree with ST's TFBGA100 recommendations. ST specifies a 0.400 mm stencil opening, 0.100–0.125 mm stencil thickness and a 0.120 mm pad escape trace example. Maximum package height is 1.20 mm. [ST DS13311 Rev 5, Tables 127–128](https://www.st.com/resource/en/datasheet/stm32h725ag.pdf)

The [official KiCad STEP model](https://gitlab.com/kicad/libraries/kicad-packages3D/-/blob/master/Package_BGA.3dshapes/TFBGA-100_8x8mm_Layout10x10_P0.8mm.step) is included unchanged. OpenCascade measures bounds x/y ±4 mm, z −0.010 to +1.102 mm: 8 × 8 × 1.112 mm. The small negative ball extent is part of that model. Use ST's 1.20 mm maximum height for clearance review. Downloaded files and SHA-256 hashes are recorded in the status file; cached originals are in `reports/bga100-assets`.

## Escape feasibility, still to route

Unlike the 0.5 mm-pitch option, the 0.8 mm grid leaves 0.40 mm between adjacent 0.40 mm pads, enough for one 0.12 mm trace with two 0.10 mm clearances. A centered 0.45 mm copper / 0.20 mm through-drill dogbone between four balls has about 0.141 mm copper-to-pad clearance and 0.266 mm hole-to-pad clearance. These calculations meet the current generic project rules without assuming via-in-pad, microvias or a special BGA exception. A 1.6 mm board / 0.20 mm nominal drill gives an 8:1 ratio. This is geometric feasibility, not a completed escape or fabricator acceptance.

Actual routes must still satisfy hole-to-copper and hole-spacing rules on every layer, continuous USB return reference, power/decoupling placement and all native DRC checks. Through-via count and usable routing space remain to be measured.

## MCU supplies

TFBGA100 exposes **VDD33USB at E8 and no VDD50USB ball**. E8 remains on +3V3; no new 5 V input is required. The external USB 3.3 V supply scheme is documented by ST. VLXSMPS remains on the L4 switch-inductor net; VFBSMPS, VCAP and VDDLDO stay on VDDLDO; VDDSMPS stays on +3V3 and VSSSMPS on GND. L3 is the separate analog ferrite. The direct-SMPS scheme applies to BGA packages; local decoupling placement and firmware startup configuration still need implementation. [ST DS13311, Table 8 and §3.7](https://www.st.com/resource/en/datasheet/stm32h725ag.pdf), [ST AN5419](https://www.st.com/resource/en/application_note/an5419-getting-started-with-stm32h723733-stm32h725735-and-stm32h730-value-line-hardware-development-stmicroelectronic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)

The independent package-supply review is recorded in `reports/mcu-bga100-supply-check.md`. It confirms no extra 5 V supply terminal should be invented and calls for reallocated local decoupling around the reduced supply-ball count.

## Reproduce

Rebuild the isolated copy from the then-current root project and run parity/DRC:

```powershell
tools/venv/Scripts/python.exe scripts/prepare_bga100_variant.py
```

Validate the existing copy without replacing it:

```powershell
tools/venv/Scripts/python.exe scripts/prepare_bga100_variant.py --validate-only
```

The script does not launch routing, alter the root project or submit the design.

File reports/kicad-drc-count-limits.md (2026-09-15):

# KiCad10 DRC counts are capped

KiCad10.0.6's `DRC_ENGINE::RunTests` assigns a per-error-code limit of **499** for clearance and unconnected items, and **199** for every other error code. `ReportViolation` enforces each cap atomically. `--all-track-errors` does not remove these limits. [Official tagged source](https://gitlab.com/kicad/code/kicad/-/blob/10.0.6/pcbnew/drc/drc_engine.cpp)

Therefore499 unconnected reports means **at least499**, not an exact remaining-route count. Two substantially different partial layouts can both display499. A count below the cap is useful for that error code, and a completed zero-unconnected native check remains an essential acceptance condition.

`scripts/score_assembly.py` now adds `saturated_types`, `counts_are_complete` and `count_limitation` to its DRC summary. Saturated categories are labelled lower bounds in issue text. Verified against v4's499 unconnected report and v8's436 report; the former is flagged capped and the latter is not.

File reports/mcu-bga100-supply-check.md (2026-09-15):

# STM32H725VGH6 supply check

The TFBGA100 package keeps the direct-SMPS circuit. Its USB supply is E8/VDD33USB; there is no VDD50USB ball. Preserve E8 on +3V3. Table 8 confirms the package terminals, and Table 12 requires 3.0–3.6 V for an active USB transceiver. [ST DS13311 Rev 5](https://www.st.com/resource/en/datasheet/stm32h725ag.pdf)

AN5419 permits external 3.3 V at VDD33USB. Tie VDD50USB to it only on packages where that pin exists; its absence requires no new 5 V connection. Keep the internal USB regulator disabled and configure USB supply readiness according to the reference manual. Provide 1 µF and 100 nF locally at E8. [ST AN5419 Rev 3, Table 2 and §2.1.4](https://www.st.com/resource/en/application_note/an5419-getting-started-with-stm32h723733-stm32h725735-and-stm32h730-value-line-hardware-development-stmicroelectronic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)

For direct SMPS, preserve VDDSMPS→+3V3, VSSSMPS→GND, VLXSMPS→L4 switch side, and VFBSMPS/all VCAP/all VDDLDO→the L4 output net currently named VDDLDO. Firmware must select direct SMPS and disable the LDO. The connection applies to LQFP/BGA packages. Place the inductor, input/output capacitors and feedback close to the balls; reconnect every supply ball. [ST AN5419, Figure 5 and §2.1.6](https://www.st.com/resource/en/application_note/an5419-getting-started-with-stm32h723733-stm32h725735-and-stm32h730-value-line-hardware-development-stmicroelectronic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)

The remap changes the supply-pin count. Existing total capacitance is not a substitute for a placement check: redistribute the available 100 nF capacitors beside each connected VDD/VCAP ball, retain output bulk, and verify effective capacitance under bias. L3 is the analog-supply ferrite; L4 is the MCU switching inductor. This is a schematic review, not a completed layout or boot test.

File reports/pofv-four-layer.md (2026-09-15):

# Four-layer thermal via-in-pad process

JLCPCB explicitly offers paid POFV on four-layer PCBs; the free default applies to six and higher layers. This is stated both in its [POFV product announcement](https://jlcpcb.com/news/free-via-in-pad-6-20-layer-pcbs-pofv) and its current [via filling guide](https://jlcpcb.com/blog/via-filling-guide). Checked 2026-09-14. No order or manufacturer acceptance of our finished layout has been obtained.

The proposed thermal via is **0.20 mm design hole / 0.40 mm copper diameter**, giving a nominal 0.10 mm annular ring. This exceeds the POFV announcement's 0.05 mm minimum and 0.075 mm preferred ring; its hole is within the stated 0.20–0.50 mm range. Maintain more than 0.45 mm separation from regular component PTH and NPTH holes, as that POFV page specifies. Four vias per eFuse exposed ground pad are a layout proposal; this process check does not establish device thermal performance.

At nominal 1.60 mm thickness, a literal 0.20 mm drill gives an 8:1 aspect ratio, within JLC's published maximum 10:1 guidance. The actual fabrication drill/finished-hole convention is still set during manufacturing preparation. [JLC aspect-ratio guidance](https://jlcpcb.com/blog/via-aspect-ratio-critical-pcb-reliability)

Use **epoxy-filled and copper-capped**, with a flat solderable plated surface. Copper-paste-filled and capped is an available alternative if thermal analysis needs it. Ordinary solder-mask tenting or ink plugging does not provide the same via-in-pad surface. JLC requests explicit notes or an image showing which vias need filling and recommends reviewing production files. [JLC via covering instructions](https://jlcpcb.com/help/article/pcb-via-covering)

## Fabrication note draft

> Four-layer nominal 1.60 mm FR-4. Select the paid epoxy-filled and copper-capped POFV option. Fill and copper-cap the 0.20 mm thermal via holes located in the exposed ground pads of U13, U14, U15 and U16, identified in the accompanying via map. Preserve a flat solderable pad surface and the specified ENIG finish. Do not fill component connector PTH slots, plated mounting holes or NPTH mechanical holes. Confirm production files before manufacture.

Update references and via map to match the final board. If other same-diameter vias should also be filled, explicitly say so; do not ask the manufacturer to infer the distinction from hole diameter alone.

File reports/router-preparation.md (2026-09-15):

# Router input preparation and limits

`scripts/prepare_router.py` produces a fresh DSN from a source PCB without saving the PCB. It first runs native KiCad DRC and stops on physical error-severity violations. It records a source SHA256; import any resulting SES only into the matching source PCB. Local generation example:

```powershell
tools/venv/Scripts/python.exe scripts/prepare_router.py --board candidates/compact-v8-45degrees/ground.kicad_pcb --output reports/router-preflight/v8-prepared.dsn
```

The adjacent `.preflight.json`, `.native-drc.json`, `.geometry.json` and `.raw.dsn` files retain the transformation evidence. Existing tracks are checked for non-octilinear segments; a listed segment is a routing-stability screen, not a physical DRC failure.

## Geometry-preserving transformations

- Clears only generated `unconnected-*` no-connect pad assignments in the in-memory router copy. All native pad/net assignments remain unchanged.
- Deduplicates coincident or contained same-net SMD lands only when the retained copper covers the removed land. J3's four overlapping GND/VBUS contact pairs are examples.
- Retains partly overlapping same-net lands as their original DSN pads. Q1's drain lands 5–9 remain intact. Their router self-overlap reports are accepted only because native KiCad confirms the physical same-net geometry.
- Removes only the redundant router pin references from DSN net lists. The original PCB and schematics keep every physical numbered pad.

Both KiCad and FreeRouting's DSN paths convex-hull custom pad polygons, so a concave custom pad is not an exact representation. The earlier fixed-wire-polygon substitute was also unsafe: FreeRouting imports these as **non-obstacle conduction areas**, despite `type fix`. The v8 post-import native check exposed three Q1 shorts and one clearance error. The exporter now retains the original partly overlapping pads. All earlier inputs using converted Q1 polygons are superseded. [KiCad exporter documentation](https://docs.kicad.org/doxygen/specctra__export_8cpp.html), [FreeRouting2.4.1 wire import](https://github.com/freerouting/freerouting/blob/v2.4.1/src/main/java/app/freerouting/io/specctra/parser/Wiring.java)

## Historical v8 input diagnosis (superseded)

Source `compact-v8-45degrees/ground.kicad_pcb`, SHA256 `cd2a79df0559fb58b395fc0a50975ad76326d69450160bec9066380c2f8ddf75`: native physical errors0, unconnected436, non-octilinear straight segments0. Fresh raw DSN router DRC reported101 violations; the original prepared DSN reported93. Removing all8 Q1/J3 self-overlap reports was not sufficient proof of correct obstacle behavior. The corrected DSN only deduplicates the four contained J3 pairs. No native PCB changes were made by either export.

The remaining router reports comprise:

| Reports | Finding |
| --- | --- |
| 88 | Same-net Pin/Via attachment reports. FreeRouting's via `attachAllowed` and pin drill-attachment rules are stricter than copper connectivity; its DRC calls every Pin a hole, including SMT pins. These are not 88 independently measured drill-spacing failures. |
| 4 | One NPTH keepout reported on four layers. KiCad exports its0.66 mm hole with a1.06 mm keepout, already including0.20 mm radial hole clearance; the router adds0.10 mm more. |
| 1 | A foreign-net via/pad copper gap reported as0.0997 mm against0.1000 mm. Native checks pass the original curved geometry; inspect rounding/shape approximation if the final route touches that margin. |

Do not silently ignore all future router reports because this particular input is understood. Do not globally enable via-in-SMD attachment to hide these reports: it can let the router propose new via-in-pad geometry requiring a different assembly process. [Pin behavior](https://github.com/freerouting/freerouting/blob/v2.4.1/src/main/java/app/freerouting/board/model/items/Pin.java), [via behavior](https://github.com/freerouting/freerouting/blob/v2.4.1/src/main/java/app/freerouting/board/model/items/Via.java), [DRC classification](https://github.com/freerouting/freerouting/blob/v2.4.1/src/main/java/app/freerouting/drc/DesignRulesChecker.java)

## Hole clearance mapping

DSN copper spacing does not directly express every KiCad custom hole constraint. For a centred circular/oval through pad, hole-to-foreign-copper clearance equals copper-edge clearance plus the pad's minimum annular ring. In this v8 board:

- Nominal connector pad dimensions suggested at least0.20 mm annular rings, but the imported result produced16 hole-clearance reports at four via/connector locations. That deduction did not hold for every effective DSN/native shape and layer. Native hole-clearance checks must decide acceptance; the exporter does not yet fully encode these constraints.
- The0.45/0.20 mm vias have0.125 mm nominal annular rings. Thus0.10 mm copper spacing implies0.225 mm via-hole-to-foreign-copper spacing, exceeding0.20 mm.
- NPTH keepouts already encode0.20 mm hole clearance and are further enlarged by the router's copper clearance, as above.

These deductions do not apply automatically after changing via size, pad offsets, inner annuli or footprint geometry. A0.25/0.15 mm via has only0.05 mm annular ring and would require at least0.15 mm copper spacing to meet0.20 mm hole clearance. A PTH ring of0.15 mm would require0.15 mm copper spacing to meet0.30 mm hole clearance. Native post-import hole and annular DRC is mandatory.

FreeRouting supports `wire`, `via`, `pin`, `smd` and `area` clearance classes; the parser explicitly does not implement a class-pair suffix such as `smd_via_same_net`. No nonexistent same-net exception flag has been added. [Verified class parser](https://github.com/freerouting/freerouting/blob/v2.4.1/src/main/java/app/freerouting/io/specctra/parser/Structure.java)

## Locked critical routes

KiCad10 exports tracks and vias with `SetLocked(True)` as DSN `type fix`. Verified by exporting all472 v8 track/via elements locked and counting472 `fix` records. USB, oscillator, switching-power and already checked local copper must be locked before handing remaining routing to FreeRouting. Copper zones are not protected physical obstacles by this mechanism.

## Normalization stability

Version2.4.1 includes per-net suppression once trace normalization hits2000 iterations, but clones reset that suppression and the all-trace normalization path has its own loop. Clean, nonoverlapping octilinear pre-routes reduce one known source of split/combine oscillation. [Normalization fix PR741](https://github.com/freerouting/freerouting/pull/741), [current implementation](https://github.com/freerouting/freerouting/blob/v2.4.1/src/main/java/app/freerouting/board/facade/BasicBoard.java)

Do not switch to2.2.4 for this symptom: a reported regression crashed on pre-routed KiCad DSN files in that version. The same reporter found2.1.0 and1.9.0 handled their test file, making2.1.0 a justified comparison baseline if2.4.1 still stalls. That is not a performance or correctness guarantee for PCBGolf. [Upstream issue759](https://github.com/freerouting/freerouting/issues/759)

## Commands

Route with `-de input.dsn -do output.ses -mp 3 --router.optimizer.enabled=false --router.fanout.enabled=false`. Supply `-da`, `--gui.enabled=false`, `--api_server.enabled=false` and a task-local profile, as `tools/freerouting/route.ps1` does. `--router.scoring.via_costs` is the verified setting path; `--router.via_costs` is invalid in2.4.1. `-mt 0` sets the optimizer thread count and does **not** disable its stage: the explicit `--router.optimizer.enabled=false` flag is required for routing-only trials, verified against pinned `GlobalSettings.java` and `RouterSettings.java` and the v8 run.

**`-drc output.json` performs DRC only and exits.** Never append it to a routing run. In2.4.1 the DRC filename is written in the process working directory even when a directory was supplied, so use the intended output directory as the working directory.

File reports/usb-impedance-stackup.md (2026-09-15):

# Verified JLC USB differential geometry

Checked 2026-09-14 with JLC's current anonymous calculator backend, using the same model, parameter configuration and WebSocket result channel as the [official impedance calculator](https://jlcpcb.com/pcb-impedance-calculator). The browser surface was unavailable; the reproducible API query is `scripts/jlc_impedance_query.py`.

## Selected stackup

**JLC04161H-3313**, nominal 1.6 mm, four copper layers, outer 1 oz, inner 0.5 oz. The selected stackup provides 0.09940 mm prepreg between either outside signal layer and its adjacent inside plane, with dielectric constant 4.1. Its core is 1.265 mm, inner copper 0.0152 mm, and outside plane copper 0.035 mm. Select this exact stackup in fabrication; the default 7628 stackup has a different spacing and needs a different calculation. [JLC stackup specifications](https://jlcpcb.com/impedance)

The live calculator's current etched-trace model for 1 oz outside copper uses a trapezoid with lower width W1 equal to the drawn width, upper width W2 = W1 − 0.5 mil, and trace thickness 1.6 mil. Its current solder-mask profile is C1 = C3 = 1.0 mil, C2 = 0.6 mil, coating Er = 3.8. These live configuration values differ from some static descriptive pages. Responses and selected material data are preserved under `reports/jlc-calculator-source/`.

## Forward-verified options

Model: `DiffEdgeCoupledCoatedMicrostrip1B`, non-coplanar differential pair, outside layer above its adjacent solid reference plane.

| Drawn trace width | Copper-edge pair gap | Calculated differential impedance | Evidence |
| --- | --- | --- | --- |
| **0.11 mm** | **0.10 mm** | **90.1581 Ω** | `jlc-usb-width011-gap010.json` |
| 0.14 mm | 0.15 mm | 90.3849 Ω | `jlc-usb-width014-gap015.json` |

The narrower option supports the USB connector escape throat. The reverse calculation for exactly 90 Ω returned 0.11079375 mm at 0.10 mm gap, within its configured ±0.5 Ω solver tolerance; using 0.11 mm was then checked independently by a forward calculation. Raw responses report `dResultValid = 1` and no calculation error. These are manufacturer-model nominal results, not measured production coupons.

## Routing application

- Route F.Cu USB over uninterrupted In1.Cu GND. Avoid slots, voids and power-plane boundaries under the pair.
- B.Cu needs its own continuous adjacent In2.Cu GND corridor. An In2.Cu +12 V plane alone does not establish the intended same-ground reference transition. Add a ground reference region and nearby ground stitching at any F/B transition.
- This model excludes adjacent same-layer coplanar copper. Keep surrounding copper sufficiently distant; if nearby pours shape the field, calculate the actual coplanar geometry instead. A practical initial clearance is at least three times the 0.0994 mm dielectric height, subject to a layout review.
- Keep connector escape width transitions short and symmetric. Do not use summed branched-net lengths as exact pair skew; use `scripts/analyze_routes.py` endpoint estimates plus native DRC.
- Encode the chosen width/gap in the USB netclass, then run native minimum copper/hole clearance checks after routing. The 0.10 mm gap is at the selected conservative trace-spacing limit, so no further narrowing is assumed.

Reproduce either result:

```powershell
tools/venv/Scripts/python.exe scripts/jlc_impedance_query.py --width 0.11 --gap 0.10 --output reports/jlc-usb-width011-gap010.json
```

The query sends only geometric calculator parameters. It does not upload board files, submit a fabrication order, or authenticate to an account.

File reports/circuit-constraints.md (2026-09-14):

# Circuit audit and constraints

Audit date: 2026-09-14. Inputs: the official source schematics, original board pad nets in `source-inventory.json`, manufacturer documents, and official KiCad libraries. Main PCB edits remain with the routing agent. Machine-readable edits and pad remaps are in `circuit-patches.json`.

## Changes completed in schematics and local libraries

| References | Original defect or excess | Implemented correction |
|---|---|---|
| U9–U12 | Five-pin amplifier symbols attached to SOIC-8 footprints; MPN belonged to a different pinout | NCS20071XV53T2G, SOT-553 footprint and STEP; existing pins 1–5 retained |
| U1, U2 | AP62300T value conflicted with AP62300WU-7 MPN and feedback values | Standard AP62300WU-7 explicitly selected; U1 divider simplified as below |
| R3, R4 | U1 divider used three parallel 100k resistors and 10k | R4 becomes 31.2k 1%; R3 becomes 10k 1%; R5/R6 removed |
| R70–R73 | 33k current-monitor loads exceeded the 3.3V ADC range during valid port loading | 10k 1% loads, with documented firmware calibration change |
| U13–U16 | Value TPS25942 conflicted with actual MPN TPS25944ARVCR | Displayed value corrected to TPS25944A; MPN and functionality retained |
| D1 | SMAJ16CA-13-F MPN attached to SMB footprint/model | Correct SMA footprint and STEP, same diode MPN and nets |
| J1 | Generic footprint did not fit specified PJ-002AH-SMT-TR; second power land was netless | Manufacturer pad geometry; both power lands numbered PWR1 |
| J3 | Original hybrid USB-C connector had duplicate terminal nets and PTH hole spacing below the selected fabricator's minimum | GCT USB4105-GF-A host receptacle; all USB2 signal contacts are SMT; exact official KiCad footprint and STEP |
| BH1–BH4 | Optional mounting-only holes blocked compact packing | Removed with their isolated wires and GND symbols, as directed by root |
| J4 | DNP CAN header | Accessible 2×4 pad interface retained; no installed header model assumed |

### Amplifier correctness

The NCS20071 SOT-553 ordering variant has pin 1 IN+, 2 VSS, 3 IN−, 4 OUT, 5 VDD. The SOT23-5 variant instead puts OUT on 1, IN+ on 3, and IN− on 4. The imported source already used the SOT-553 mapping; merely shrinking to the source MPN's SOT23-5 would have made the circuit wrong. The corrected footprint preserves the existing input/output nets. [onsemi NCS20071 datasheet, Figure 1](https://www.onsemi.com/download/data-sheet/pdf/ncs20071-d.pdf).

Exact amplifier routing:

| Device | IN+ pin 1 | IN− pin 3 | OUT pin 4 | Power |
|---|---|---|---|---|
| U9 | `Net-(U9-+)`, R50.2 | `Net-(U9--)`, R51.2/R52.1 | `Net-(R62-Pad1)` | 2 GND; 5 +12V |
| U10 | `Net-(U10-+)`, R53.2 | `Net-(U10--)`, R54.2/R55.1 | `Net-(R63-Pad1)` | same |
| U11 | `Net-(U11-+)`, R56.2 | `Net-(U11--)`, R57.2/R58.1 | `Net-(R64-Pad1)` | same |
| U12 | `Net-(U12-+)`, R59.2 | `Net-(U12--)`, R60.2/R61.1 | `Net-(R65-Pad1)` | same |

These amplify/indicate CAN bus behavior. Do not remove the surrounding resistor networks as apparently redundant parts.

### Regulators

AP62300 has nominal 0.800V feedback; AP62300T uses 0.763V. The output equation is `Vout = Vfb × (1 + Rtop/Rbottom)`. U1 now computes to 3.296V. Its resistor-only worst-case range is approximately 3.247–3.346V; reference tolerance and load regulation also apply. U2 remains 52.3k/10k and computes to 4.984V. The original U1 combination of a non-T MPN and three parallel 100k top resistors computed to 3.467V. [Diodes AP62300 datasheet, output selection and ordering table](https://www.diodes.com/datasheet/download/AP62300.pdf).

Keep C4/C9 across BST/SW immediately at U1/U2. Keep input capacitors close to VIN/GND, L1/L2 close to SW, and feedback traces separate from switching copper. Output capacitors serve both stability and load transients. Do not shrink their effective capacitance without checking DC-bias derating. The 5V converter supplies the 3.3V converter; this is a cascade, not two independent 12V converters.

L1/L2 are 3.3µH MEKK2520T3R3M, now catalogued as LSENC2520KKT3R3M: 1.8A rated current, 1.8A specified saturation current at 30% inductance reduction, 2A thermal-rise rating, 0.144Ω maximum DCR. Retaining the part does **not** establish a 3A continuous output rating for the assembled regulator. At nominal 12V→5V, 3.3µH, 750kHz, computed ripple is about 1.18A peak-to-peak; a 1A load already reaches about 1.59A peak. Validate actual rail loading before further reducing inductors. [Taiyo Yuden current product page](https://ds.yuden.co.jp/TYCOMPAS/or/detail?pn=LSENC2520KKT3R3M&u=M).

### Port current sensing and protection

The specified TPS25944A uses circuit-breaker behavior; TPS25942 uses current limiting. Nominal trip setting is approximately `89/R_ILIM[kΩ]`; existing 28k gives 3.18A per channel. IMON nominal gain is 52.3µA/A. Old 33k burden resistance produced 1.726V/A; the corrected 10k produces 0.523V/A. [TI TPS25942/44 datasheet](https://www.ti.com/lit/ds/symlink/tps25944a.pdf).

**Firmware must use `current_A = adc_voltage_V / 0.523`**, equivalently approximately 1.912A/V. A conversion previously calibrated to the same IC with 33k must be multiplied by 3.3. Validate against known loads. The four channels remain independently enabled and independently measured. This change does not authorize raising the current limit or total input rating.

Exact monitor signals: U13.19→CH1_IMON→U3.47, U14.19→CH2_IMON→U3.50, U15.19→CH3_IMON→U3.52, U16.19→CH4_IMON→U3.45. Their loads R70/R71/R72/R73 terminate at GND. Keep quiet measurement returns separated from high-current voltage drops by placement and copper routing, while retaining one continuous ground reference.

The main +12V path runs J1→Q1→U13–U16→four OBD-C VBUS groups. Main input current is the sum of channel loads plus electronics, not one channel current. Use broad pours and multiple parallel vias wherever a layer transition is unavoidable. A tiny generic signal trace on this path is unacceptable. The source input jack is rated 5A total, so four 3.18A limits do not imply permission to draw 12.7A simultaneously. Q1 is SI7101DN, a low-resistance P-channel part; its current capability depends on thermal copper and temperature. [Vishay SI7101DN datasheet](https://www.vishay.com/docs/63232/si7101dn.pdf).

## Interface and routing constraints

### OBD-C is a proprietary full-contact Type-C interface

J5–J8 require **all signal contacts**, including the eight contacts normally used for SuperSpeed. A cheap USB2-only 6/12/16-pin connector is incompatible. Preserve this mapping on every OBD-C connector:

| Contacts | Function |
|---|---|
| A2/A3 | CAN0_H / CAN0_L |
| A11/A10 | CAN1_H / CAN1_L |
| B2/B3 | CAN2_H / CAN2_L |
| B11/B10 | CAN3_H / CAN3_L |
| A6+B6 / A7+B7 | Channel USB D+ / D− |
| A8 / B8 | Channel SBU1 / SBU2 ignition and relay circuitry |
| A4+A9+B4+B9 | Channel-switched +12V |
| A1+A12+B1+B12 and shield | GND |
| A5/B5 | Source NC; preserve |

Preserve the four CAN transceivers, common-mode chokes L5–L8, and common CAN buses across all four ports and J4. Keep connector access and plug overmold clearance; bare receptacle bodies fitting does not prove four cables can mate simultaneously.

### USB hub

USB2517 needs five downstream connections: four OBD-C ports plus the MCU on port 7. Ports 5/6 are unused. A four-port hub is not a replacement unless extra hub hardware is added. Preserve the +3V3 supply bypassing, 1.8V internal regulator output capacitors, R27 12k bias resistor, and 24MHz Y2 network. Do not drive other loads from the internal 1.8V outputs. Unused ports should be disabled in configuration. [Microchip USB2517 hardware checklist](https://ww1.microchip.com/downloads/en/DeviceDoc/USB2517-Hardware-Design-Checklist-00004211.pdf).

Exact differential pairs:

| Pair | Endpoints |
|---|---|
| USB_D_N/P | J3 A7/B7 and A6/B6 → U4.58/59 |
| CH1_D_N/P | U4.1/2 → J5 A7/B7 and A6/B6 |
| CH2_D_N/P | U4.3/4 → J6 |
| CH3_D_N/P | U4.6/7 → J7 |
| CH4_D_N/P | U4.8/9 → J8 |
| STM_D_N/P | U4.55/56 → U3.100/101 (PA11/PA12) |

Route each pair together over continuous ground. Use stackup-derived impedance, short matched paths, minimal layer changes, and short connector-pin joins rather than branched stubs. Keep switch-node copper away. A generic autorouter's successful connection report does not verify differential impedance or skew. J3 CC1 uses R31||R32=5k to GND; CC2 uses R44||R45=5k. They must remain separate. J3 VBUS is host-detect power only; never join it to the 12V OBD-C bus.

### Connector dimensions and thickness

J1 corrected footprint follows the manufacturer's drawing: four lands 2.5×4mm, 6mm row separation, 17mm outer span, and 1.7/1.8mm locating holes. Two lands are physical terminal 1. Nominal PCB thickness is 1.6mm; body height is 11mm. The source generic footprint was materially smaller. [Same Sky PJ-002AH-SMT-TR drawing](https://www.sameskydevices.com/product/resource/pj-002ah-smt-tr.pdf).

J5–J8 MPN 10132328-10011LF is an 8.8mm-high vertical receptacle, manufacturer-listed PCB thickness 1.57mm, rated 5A on VBUS/GND. Its board-side tail geometry must be respected. [Amphenol product](https://www.amphenol-cs.com/product/1013232810011lf.html), [manufacturer drawing](https://cdn.amphenol-cs.com/media/wysiwyg/files/drawing/10132328.pdf).

J3 is now **GCT USB4105-GF-A**, a USB2 Type-C top-mount receptacle. The original unused SuperSpeed contacts are omitted; CC1, CC2, USB D+/D−, VBUS, GND and grounded shell are preserved. This substitution applies only to host J3: J5–J8 still require 24 contacts. The standard GF-A variant has 0.95mm shell stakes, 3.31mm height, and 8.94mm width. The official KiCad footprint has a 10.64×8.94mm courtyard, 0.20mm minimum signal-pad gaps, and four 0.60mm-wide plated shell slots with 0.20mm annular rings. This avoids the original JAE's 0.40mm gap between plated holes, below JLCPCB's published 0.45mm minimum. [GCT manufacturer drawing](https://gct.co/files/drawings/usb4105.pdf), [official KiCad footprint](https://gitlab.com/kicad/libraries/kicad-footprints/-/blob/master/Connector_USB.pretty/USB_C_Receptacle_GCT_USB4105-xx-A_16P_TopMnt_Horizontal.kicad_mod), [JLCPCB capabilities](https://jlcpcb.com/capabilities/pcb-capabilities).

The downloaded GCT drawing was visually checked against the footprint. OpenCascade measures the matching STEP at x=±4.470mm, y=−3.675…4.105mm, z=−0.950…3.310mm. Retain the current 1.6mm PCB for the verified J1 and J5–J8 mounting geometry; J3 no longer creates an additional thickness restriction. The earlier JAE duplicate-pad repair is superseded and its footprint is unused.

Native DRC found the stock GCT shared outer ground lands only 0.1944mm from locating holes. Those four logical pads (A1/B12 and A12/B1) now use capsule ends, roundrect ratio 0.5, retaining their 0.60×1.15mm envelope and both 0.65mm holes. Calculated nominal copper-to-hole clearance is 0.23296mm. All other pads retain stock geometry.

## MCU miniaturization branch

Retaining every existing pin function is the low-risk electrical approach. UFBGA169, 7×7mm, is the leading replacement for the 20×20mm LQFP144 body. STM32H725AGI6 is an active orderable variant. PG9/PG10, used for CAN2 here, are absent from the 100-pin and WLCSP115 package pin tables; those packages require a redesigned pin allocation. The MCU has three FDCAN controllers; source CAN1 (PB5/PB6) and CAN3 (PB12/PB13) use alternative pins of FDCAN2. Do not claim four simultaneously independent MCU CAN controllers. Source behavior can select the transceivers. [ST datasheet](https://www.st.com/resource/en/datasheet/stm32h725zg.pdf), [ST product page](https://www.st.com/en/microcontrollers-microprocessors/stm32h725ag.html).

A BGA branch must preserve the SMPS/VCAP/VDDLDO topology, all power balls, PA11/PA12 USB, SDMMC pins, analog monitor inputs, and boot button. Escape routing, thermal ground connections, and a verified fabricator stackup determine whether its saved area outweighs via/layer penalties. The existing BOOT0 button and USB programming path should remain usable; the source does not expose SWD/NRST.

The separate `mcu-bga-remap.json` now records all 144 original pins, their exact functions/nets, and all 169 target ball assignments with pad coordinates. All original functions exist; 104 connected source pins become 103 connected target balls because the number of repeated supply pins differs. Repeated supply functions are assigned as groups. The official KiCad 9.0.4 symbol and footprint have been saved, and selected critical assignments were corroborated against ST Table 8. Main U3 remains unchanged.

The available legacy official KiCad STEP measures 7×7mm with top z=0.75mm, while the current ST drawing gives 0.53mm nominal/0.60mm maximum package height. It is flagged as a conservative placeholder, not an exact model. The 0.27mm pads match ST's recommendation; at 0.50mm pitch they leave only 0.23mm between adjacent pad edges. A route with 0.10mm clearance on each side would have just 0.03mm remaining width, so ordinary routing between adjacent balls is impossible. A branch must prove its fanout using diagonal dogbones, NC pad locations, and the selected fabricator's actual rules.

## Verification and remaining limits

All modified KiCad s-expressions parse. All five sheets export netlists using KiCad 10.0.6. The official files are five independent schematic roots, so **exporting only `pcbgolf.kicad_sch` exports the power section, not the full board**. Each sheet's exported netlist is in `reports/pcbgolf*.net.xml`.

Power-sheet ERC has zero reported violations under project settings. Separate other-sheet ERC reports include unresolved project-library context, isolated cross-sheet labels, undriven supplies, and VCAP power-output pin-type conflicts. This is not a whole-design clean ERC claim. Source PCB connectivity remains the reconciliation authority until sheets are integrated and all endpoint mappings are verified.

No prototype has been powered or signal-integrity tested. Required final evidence includes full connectivity/DRC, exact component-body and connector-clearance geometry, power-path widths and thermal assessment, hub enumeration, USB traffic, SD access, each port's enable/current readback, CAN operation, ignition/relay outputs, and simultaneous mating accessibility.

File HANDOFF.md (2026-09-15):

# PCBGolf handoff

**Owner: [ExplodingCB](https://github.com/ExplodingCB). Branch: `work/compact-pcba`. Stopped September 14, 2026 at the owner's request.** All three subagents are interrupted and the router has exited. The latest instruction is to push the work and plan for another engineer, not to continue automatically.

## Start here

Open **[work-in-progress/pcbgolf.kicad_pro](work-in-progress/pcbgolf.kicad_pro)**. The repository-root project is an older placement. All five schematics, symbols, footprints, models, rules and assembly STEP are included.

**This is not a valid leaderboard entry.** There has been no submission, upstream PR, fabrication order or hardware test. Open connections prevent the current board from working.

| Check | Latest result |
| --- | --- |
| PCB | 45 × 37 mm, four layers, 1.6 mm thick |
| Assembly bounds | 45.0000001 × 37 × 14.2300002 mm |
| Components | 239; 236 populated model instances |
| Copper | 2,715 track segments, 484 through vias |
| Missing connections | **184 pad-group connections across 113 nets** |
| Native physical DRC | **0 errors**, 399 other warnings, 184 unconnected items |
| Five-sheet schematic parity | Passed: 0 component differences, 0 pin/net differences |
| Mechanical screen | No component AABB collisions |
| USB reference screen | 17/17 return vias connected; **1 flagged reference gap** |
| Firmware | Bootstub/application compile and link; untested on hardware |

Current evidence is in `work-in-progress/drc.json`, `net-groups.json`, `connectivity-parity.json`, `usb-reference-audit.json`, `step-component-bounds.json`, and `reports/checked-wip-mechanical-audit.json`. All 239 component placements exactly match the existing assembly STEP; only routing changed after export. Cable access is separately screened in `reports/actual-placement-mating-audit.json`: 0.5 mm between conservative USB-C overmold envelopes and a 0.35 mm closest plug-to-J1 envelope gap.

## Exact saved state

- **Main checked result:** `work-in-progress/pcbgolf.kicad_pcb`, the last completed `via400` router output.
- **Exact pre-route source:** `work-in-progress/routing-source.kicad_pcb` plus matching project/rules, 191 missing connections.
- **Reproduction:** `work-in-progress/routing-handoff/via400.dsn`, `.ses`, `.preflight.json`, and `via400-router.log`. Original absolute paths identify the producing machine; the hash matches the included source copy.
- **Earlier small-via experiment:** `work-in-progress/small-via-trial.*`, 190 opens, zero physical DRC errors. It shrank 130 unlocked low-current signal vias to 0.30/0.15 mm without breaking connected pad groups. This predates the last main result. Reapply its script to the main board rather than reverting to this older trial.
- `pcbgolf.merge.json` records only the initial critical-route merge, not the current final routing state.

The last router run finished at 22:01 local with a ten-minute timeout. Native opens improved **191 → 184**; router-internal counts were **184 → 177**. Native KiCad is authoritative. No 0.30/0.15 mm autorouting run was started. **No six-layer conversion was implemented.** All other candidates remain locally under ignored `candidates/`.

## Proposed continuation plan — not executed

1. Prioritize a complete working entry over further size optimization. Keep the current mechanical envelope initially. Use `net-groups.json` to find isolated pads and incomplete power/CAN branches. Repeating unchanged four-layer routing settings has produced only small gains.
2. The last proposed direction was **six layers**, accepting +10,000 layer penalty for routing capacity and reference/power planes. JLC's [JLC06161H-3313](https://jlcpcb.com/impedance) has the same nominal 0.09940 mm outer prepreg as the current four-layer impedance model. Signal / ground / signal / mixed power-and-signal / ground / signal is a starting point, not a finished design. Map all existing inner copper explicitly, protect USB references and recheck connectivity. `stackup_trial.py` is an older experiment that refuses already-routed inner layers; do not run it blindly. Many helpers hardcode four layers.
3. A smaller alternative is `compact_signal_vias.py` on the latest main board, followed by `prepare_router.py --allow-filled-via-in-pad --routing-via-mm .3 --route-width-mm .1`. The prior shrink experiment passed native physical DRC. Review filled/capped processing and actual drill clearances. Thin router search widths do not qualify power current capacity.
4. Complete every signal and power/ground pad group. Preserve checked USB, MCU SMPS and crystal geometry. Engineer power trunks, return paths and thermal connections. Clean up dangling copper, library mismatches and silkscreen after routing stabilizes.
5. On one final artifact, run native full DRC, uncapped connectivity, five-sheet parity, USB endpoint/skew/reference checks, power/current review, firmware review and final mechanical/mating checks. Regenerate the complete STEP, calculate score from the exact PCB/STEP, and package the self-contained KiCad project plus STEP ZIP.
6. Submit through the official form under the owner's identity. Organizers review competitive entries before posting; submitting does not instantly place a score on the leaderboard.

## Critical electrical details

- MCU is **STM32H725VGH6**, 8 × 8 mm TFBGA100, 0.8 mm pitch, bottom side. The schematic package/pin remap matches the latest board. There are 82 connected and 18 NC MCU pins.
- MCU Y1 is **25 MHz**, matching firmware. Preserve the checked PH0/PH1 clock routes. Cluster positions: Y1 (3.6,15.35), C14 (3.6,17.4), C17 (1.0,16.3), C19 (4.05,24.3). U4 has its own **24 MHz Y2**. Its XTAL2 path was about 18.25 mm with two vias in the earlier checked input and needs separate layout review.
- Important repaired integration bug: USB GND return vias at **(3.2,5.6), (18.2,5.6), (25.7,5.6)** had been assigned to VBUS. They are restored and set free (`SetIsFree(True)`) to preserve explicit nets during zone fills. Keep this behavior when copying/adding vias.
- Frozen USB manifest: `reports/usb-paired-routes.json`, 223 segments, 40 signal vias, 17 ground return vias and reference patches. Native DSN export omits track-only keepouts; `prepare_router.py` explicitly exports them.
- Remaining USB reference flag: track 142, `CH3_D_P`, bottom, approximately **0.01114 mm²** near x=19.98–20.21 / y=9.20–9.28, between two signal-via antipads. It has not been resolved or waived. All 17 returns connect to both original inner layers. Nominal pair impedance was 90.16 ohms with 0.11 mm width / 0.10 mm gap and JLC04161H-3313; final compliance is not established.
- J1 **PJ-002AH-SMT-TR is 5 A total**. Four TPS25944A trips are about 3.18 A each; their sum is not an allowed input load. Power/return copper and thermal spreading remain unqualified.
- U1/U2 AP62300 ICs are rated 3 A, but existing inductors are approximately 1.8 A saturation / 2 A thermal. Do not claim usable 3 A rails. The 3.3 V buck is fed from 5 V. Feedback, TVS, op-amp footprint and IMON values were corrected; see circuit reports. R70–73 are 10 kΩ.
- Local `VLXSMPS` loop and part of `VDDLDO` are connected; decoupling/supply connections still need review. `audit_power_copper.py` checks geometric connectivity, not ampacity.
- Four CAN transceivers use three MCU controllers with alternate FDCAN2 allocation. J4 DNP header pads remain.
- Some vias overlap SMD lands and need **filled and capped via-in-pad processing**. A complete final processing map is missing. Generic tenting defaults do not constitute sufficient fabrication instructions.
- Native DRC has two library-footprint mismatch warnings and numerous silkscreen/dangling-copper warnings. Do not disable manufacturing checks to obtain a clean report.

## Firmware

`firmware/pcbgolf/` includes the board header, patch, build driver and pinmap. Panda revision `78cf69904c332c599a297fcc2a09c08d10d429d5`, opendbc `057aee25b5eee7530f0b95b5b508c8c3247b0cd7`, Arm GNU 12.3.Rel1. Bootstub/application compile and link. `audit_firmware_pinmap.py` checked 44 GPIO/ADC/CAN allocations against schematic allocation and ST data.

Both images require `PCBGOLF_BGA100`: this **H725 uses SMPS**, overriding panda's historical TFBGA100 supply heuristic. USB 3.3 V is external; this package has no VDD50USB ball. Hardware behavior, peripheral coverage including microSD/hub, timing and analog calibration remain unverified. No qualified firmware binaries are published.

## Tools and reproduction

Original workspace: `D:\Projects\PCBGolf`. Installed toolchains remain locally in ignored `tools/` and are not pushed.

- KiCad **10.0.6**: `tools/kicad/bin/kicad-cli.exe` and `tools/kicad/bin/python.exe` (Python 3.11, pcbnew, Shapely).
- Python **3.12** venv: `tools/venv/Scripts/python.exe`; numpy 2.5.3, scipy 1.18.1, Shapely 2.1.2, sexpdata 1.0.2, cadquery-ocp 8.0.1.0.0.
- Java **25**: `tools/java/jdk-25.0.4.1+1-jre/bin/java.exe`.
- FreeRouting **2.4.1**: retained original plus bounded JAR. `bound_router_cleanup.py` changes only two existing normalization guards from 2000 to 64 to prevent oscillation stalls. Original SHA-256: `251101c3eeac22d7e7dfcf6796603279e5d1000283eb82d8f093780f7afc6aa9`; bounded SHA-256: `af6a1e173349957b94580b6b8893c212c08502ca9afdb144569c439202d5f21e`.

From repository root, adjusting executable paths on another machine:

```powershell
tools/kicad/bin/kicad-cli.exe pcb drc --format json --severity-all --all-track-errors --refill-zones --output review-drc.json work-in-progress/pcbgolf.kicad_pcb
tools/kicad/bin/python.exe scripts/audit_net_connectivity.py work-in-progress/pcbgolf.kicad_pcb --out review-net-groups.json
tools/venv/Scripts/python.exe scripts/validate_connectivity.py --board work-in-progress/pcbgolf.kicad_pcb --project work-in-progress/pcbgolf.kicad_pro --output review-parity.json
tools/kicad/bin/python.exe scripts/import_route.py work-in-progress/routing-source.kicad_pcb work-in-progress/routing-handoff/via400.ses --out work-in-progress/reimport.kicad_pcb --preflight work-in-progress/routing-handoff/via400.preflight.json
```

Use the custom five-sheet parity check, not the single-top-level KiCad parity flag. Native pad-group counting excludes orphan copper and cannot replace DRC. SES import checks the source hash and restores tiny footprint-coordinate rounding; never import into a different-placement source.

Last router settings: `-mp 10`, `--router.job_timeout=00:10:00`, optimizer/fanout disabled, neck width 100 µm, hole clearance 200 µm, edge clearance 300 µm, `--router.scoring.unrouted_net_penalty=100000000`. Both DSN `(attach on)` and `(control (via_at_smd on))` are required for via-in-pad routing. Router scores are higher-is-better and unrelated to the challenge score. See the saved log and `reports/SOLO_COMPLETION.md` for history.

## Submission and identity

[Rules/ZIP requirements](https://github.com/commaai/PCBGolf#submission), [leaderboard](https://comma.ai/leaderboard#pcbgolf_challenge), [official form](https://docs.google.com/forms/d/e/1FAIpQLSc_Qsh5egoseXKr8vI2TIlsskd6nNZLNVuMJBjkogZzLe79KQ/viewform).

The form requires Google authentication. GitHub identity **ExplodingCB** is authorized, but no prize-contact email has been verified. Do not use the GitHub noreply commit address as contact email. Local `gh` was authenticated as ExplodingCB; the connected GitHub MCP was a different identity and was not used for publishing.

**Latest instruction: push the current work and plan for another engineer. This session is stopped.**

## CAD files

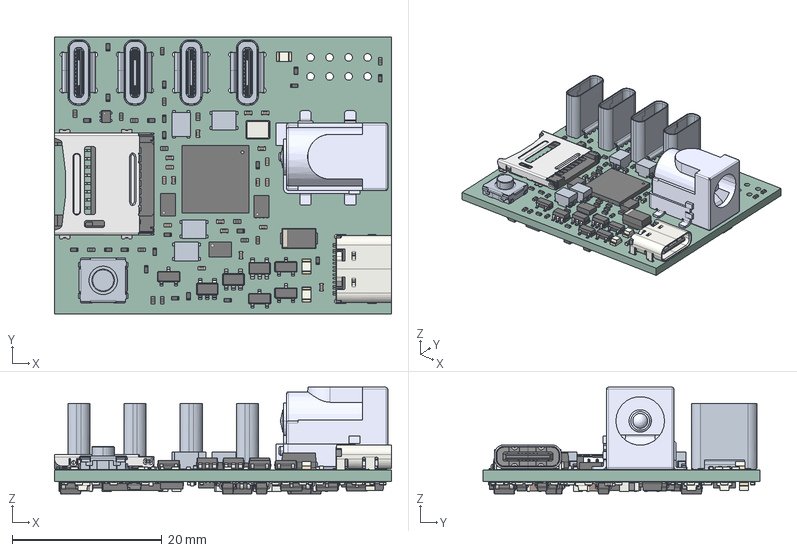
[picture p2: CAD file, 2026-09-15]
work-in-progress/assembly.step
45.0 x 37.0 x 14.2 mm
QFN-64-1EP_9x9mm_P0.5mm_EP4.1x4.1mm
R_0402_1005Metric x 123
C_0402_1005Metric x 38
DFN-8-1EP_3x2mm_P0.5mm_EP1.7x1.6mm x 4
SOT_23_5 x 8
USB_C_Receptacle_16P_TopMnt_Horizontal_GCT_USB4105-xx-A
LED_0805_2012Metric x 8
ubN}p@ACT1210 DRK180705 x 4
ubN}p@ACT1210[q x 8
ubN}p@ACT1210[q2 x 8
3.9maxp[q x 16
CUI_DEVICES_PJ-002AH-SMT-TR
Crystal_SMD_3225-4Pin_3.2x2.5mm x 2
10132328--100X2LF x 4
D_SMA
SOT-23-3 x 8
SOT_553 x 4
EVQQ2-BFKPUY-03W
QFN-20-1EP_3x4mm_Pitch0.5mm x 4
C_0805_2012Metric x 13
TFBGA-100_8x8mm_Layout10x10_P0.8mm
L_Cenker_CKCS201610
CLMVC-FKA-CL1D1L71BB7C3C3
L_1008_2520Metric x 2
L_0603_1608Metric
SIS468DN-T1-GE3
SOT_23_6 x 2
D_SOD_123F
pcbgolf_PCB

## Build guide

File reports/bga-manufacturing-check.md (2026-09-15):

# STM32H725AGI6 BGA manufacturing screen

Checked 2026-09-14 against JLCPCB primary sources. Target: UFBGA169, 0.50 mm pitch, 0.27 mm NSMD lands, nominal 1.60 mm FR-4. This is a process feasibility screen, not fabrication acceptance.

## Decision

The exact combination is **not yet established as manufacturable under the published generic rules**. A compact BGA experiment can proceed in isolation, but a score or successful autoroute must not be treated as fabrication qualification. The two unresolved points are dense BGA escape clearance and the actual drilling process for 0.15 mm design holes through 1.60 mm material.

## Published capability and selected process

JLC lists 0.15 mm via holes with 0.25 mm copper diameter, giving a nominal 0.05 mm annular ring. It prefers 0.20 mm holes and a diameter difference of 0.15 mm. Generic via-hole-to-track and inner via-hole-to-copper clearance are both 0.20 mm. Multilayer 1 oz trace/space is 0.09/0.09 mm; local 3 mil BGA fanout traces are permitted, while BGA pad-to-trace clearance is at least 0.09 mm. These minima are separate from the much larger component-PTH annular-ring requirement. [JLC manufacturing capabilities](https://jlcpcb.com/capabilities/pcb-capabilities)

For a via inside a solder land, specify **epoxy-filled and copper-capped POFV**, or copper-paste-filled and capped. JLC's covering guide identifies those processes as suitable for BGA/SMT holes, gives a maximum 0.50 mm plugging-hole size, and requires order remarks identifying the holes to fill. Ink plugging is unsuitable for holes in pads or within 0.35 mm of pad openings. Free resin filling is offered on six-layer and higher boards; a four-layer experiment must explicitly obtain that process in its quote rather than assume ordinary tenting is sufficient. [JLC via covering, updated September 9, 2026](https://jlcpcb.com/help/article/pcb-via-covering)

Use ENIG for this experiment. Preserve the manufacturer land pattern; shrinking solder lands to create route channels also requires an assembly/land-pattern justification.

## Calculated escape geometry

The calculations below are geometric deductions, not additional manufacturer rules. All distances are millimetres.

| Pattern | Available geometry | Result against generic rules |
| --- | --- | --- |
| Trace between 0.27 lands on 0.50 pitch | Gap = 0.50 − 0.27 = **0.23** | 0.09 trace + two 0.09 gaps needs **0.27**; fails |
| Local 3 mil trace between those lands | 0.0762 + 2 × 0.09 = **0.2562** | Still exceeds **0.23** gap |
| 0.25-diameter dogbone via centred between four balls | Diagonal centre distance = 0.50 / √2; copper gap = distance − 0.135 − 0.125 = **0.09355** | Below conservative 0.10 via-copper gap; drill-to-land gap with 0.15 hole is only **0.14355**, below generic 0.20 |
| 0.09 trace between 0.15 holes on 0.50 pitch | Hole-edge clearance on either side = (0.50 − 0.15 − 0.09) / 2 = **0.13** | Below generic **0.20** hole-to-track clearance |
| Same route using a 0.20 hole | (0.50 − 0.20 − 0.09) / 2 = **0.105** | Larger drilling does not solve the routing gap |

Deleting unused inner-layer copper annuli cannot remove a through-hole barrel or relax the drill-to-copper clearance. Sparse fanout may still be feasible if the actual assigned pins leave larger channels; assess the exact ball map and routed geometry, not only the grid pitch.

JLC's September BGA guide illustrates 0.15/0.25 mm filled vias and 0.09 mm inner traces after removing unused inner pads. It simultaneously recommends trying for outer via diameters of at least 0.35 mm. The dense-grid example does not state an exception to the generic 0.20 mm hole clearance. Therefore it cannot by itself authorize a custom 0.13 mm DRC limit. [JLC BGA design guidelines, updated September 9, 2026](https://jlcpcb.com/help/article/bga-design-guidelines---pcb-layout-recommendations-for-bga-packages)

The same conflict appears in a customer question on JLC's site; the publicly returned page contains no answer. It is evidence of ambiguity, not evidence of approval. [Unanswered inner-layer BGA clearance question](https://jlcpcb.com/help/answers/detail/943-0.5mm-BGA-copper-to-hole-clearance-on-inner-layers)

## Board thickness and drill interpretation

JLC's aspect-ratio article specifies the **pre-plating mechanical drill diameter** as the denominator and states a 10:1 limit in its own capability guidance. For a literal 0.15 mm mechanical drill, 1.60 / 0.15 = **10.67:1**; 0.20 mm gives **8:1**. A 1.20 mm board and literal 0.15 mm drill would also be 8:1, but board thickness must remain compatible with the selected connectors and stackup. [JLC via aspect ratio, updated April 22, 2026](https://jlcpcb.com/blog/via-aspect-ratio-critical-pcb-reliability)

The design hole value may be treated differently from the production drill, because copper plating reduces hole diameter and fabricators can apply compensation. Do not infer the compensated drill, or claim rejection solely from the nominal ratio. Obtain the selected process's actual drill/finished-hole interpretation and approved thickness together. The public generic table does not prove the simultaneous 1.60 mm / 0.15 mm combination.

## Evidence needed to close the screen

For a layout using the dense pattern, a manufacturing review must identify the actual layer count/stackup, 1.60 mm thickness, 0.15 mm design-hole convention, production drill, 0.25 mm via copper, 0.27 mm BGA lands, removal of unused inner annuli, and the smallest **actual** hole-to-track and hole-to-plane gaps. It must explicitly accept the filled/capped process and any clearance below 0.20 mm. Retain that acceptance with the final fabrication package. No such acceptance has been obtained in this task.

Until then, keep the generic 0.20 mm hole clearance enabled. Do not waive BGA DRC failures or silently assign a smaller region-specific hole clearance merely to let the router finish.

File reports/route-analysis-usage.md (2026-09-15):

# USB route and power-width analyzer

Run after importing a routing session into its matching PCB:

```powershell
tools/venv/Scripts/python.exe scripts/analyze_routes.py --board candidates/compact-v4-planes/pcbgolf.kicad_pcb --output candidates/compact-v4-planes/route-analysis.json
```

The script reads the board without saving changes. It uses bundled KiCad Python to obtain native pad positions/polygons, copper layers and track/arc lengths; graph and proximity analysis run in the local Python environment.

It reports all six pairs from `reports/circuit-constraints.md`: `USB_D_N/P`, `CH1_D_N/P` through `CH4_D_N/P`, and `STM_D_N/P`.

If a package variant changes the MCU endpoint pin number, the analyzer can resolve a unique pad on the same MCU component and net. Every such remap is recorded in `endpoint_resolution`. Ambiguous or missing endpoints remain incomplete. Connector A/B contact numbers are always preserved. This supports the MCU BGA experiment without asserting that the schematic/package remap is correct; validate that separately.

- **Total track length per net:** all routed segments and branches, plus via counts and occupied layers. This is **never labelled exact skew**.
- **Endpoint paths:** shortest connected centerline path from the hub pin to each corresponding connector A/B contact, or the MCU pin. Duplicate connector pins have separate paths. Missing routes produce null lengths.
- **Pair mismatch:** differences between corresponding N/P endpoint paths. Travel within pad copper and copper zones is omitted; these are geometric estimates, not electrical-delay measurements.
- **Layer changes:** vias and plated component pads traversed by each shortest path. A separate barrel-length estimate assumes evenly spaced copper layers across nominal board thickness.
- **Obvious uncoupled routing:** sampled same-layer proximity and parallelism. Defaults are a maximum 0.50 mm copper-edge gap, 15° direction difference and 0.25 mm sampling interval. These are screening thresholds, not a controlled-impedance specification. Tune with `--max-pair-gap`, `--max-parallel-angle` and `--sample-spacing`.
- **Power copper:** minimum/maximum/distinct track widths, lengths, layers, via dimensions and zone counts for `+12V`, `+5V`, `+3V3`, `CH1_12V` through `CH4_12V`, plus discovered legacy channel-output names.

Zones are counted but are not traversed by the route graph. Power-plane neck widths, thermal spokes, current-sharing and copper thickness require separate analysis. Arc centerlines are sampled to at most 0.001 mm chord error; native arc lengths set the corresponding graph weights. Overlapping copper joins and pad connections can introduce small geometric shortcuts, so preserve the report's qualifications.

Verification: a synthetic branched net showed distinct hub-to-A and hub-to-B path lengths while retaining the larger total net length; a separate via transition reported the correct count/layers; parallel and widely separated test pairs produced the expected uncoupling results. The initial v4 board correctly reports incomplete USB paths while it is unrouted. Run KiCad DRC and combined-sheet connectivity validation separately before using the results for a final design review.

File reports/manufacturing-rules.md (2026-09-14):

# Draft fabrication rules and power-copper recommendations

## Result and scope

`reports/jlc4layer.kicad_dru` is a syntax-checked draft for **four-layer rigid FR4, 1 oz outer copper, through vias**. It is not a fabrication approval or electrical/thermal certification. Only isolated copies under `reports/manufacturing-rule-validation/` were changed. Source and active candidate boards were not modified.

KiCad 10.0.6 accepted the file and completed native DRC without parsing errors. On the older compact-v2-4l candidate it found 12 component-pad annular-ring failures, 15 hole-spacing failures and 17 hole-to-copper failures. These are useful findings, not a clean-board claim. A separate probe confirmed that a **0.075 mm via annular ring passes**, while the component PTH minimum still rejects the old J3 rings near 0.10 mm. Logs, JSON and the isolated test boards are retained in the validation directory.

## Fabrication constraints in the draft

The source is the current [JLCPCB rigid capabilities table](https://jlcpcb.com/capabilities/pcb-capabilities), checked September 14, 2026.

| Item | Draft requirement | Interpretation |
|---|---:|---|
| Copper trace/space | 0.10/0.10 mm | Conservative relative to published 4-layer 1 oz capability |
| Copper to routed edge | 0.30 mm | Project margin above the published 0.20 mm |
| Via hole to foreign-net copper | 0.20 mm | Applies from the hole perimeter |
| Component PTH hole to foreign-net copper | 0.30 mm | Covers 0.28 mm outside and 0.30 mm inside conservatively |
| Mechanical hole separation | 0.20 mm | Default, including via pairs |
| PTH component hole to another PTH component hole | 0.45 mm | Separate condition from vias |
| Via drill / pad diameter | 0.15 / 0.25 mm minimum | Smallest process has extra cost; defaults remain 0.20 / 0.45 mm |
| Via annular ring | 0.05 mm minimum | Does not relax the component-pad rule |
| Component PTH annular ring | 0.15 mm minimum | **Four-layer only**; use 0.18 mm for two-layer 1 oz |
| Plated slot minor dimension | 0.35 mm | Four-layer process |
| NPTH round hole / routed slot | 0.50 / 1.00 mm | Mechanical minima |
| Different-net SMD pad gap | 0.15 mm | Distinct from ordinary track clearance |

Blind, buried and microvias are disallowed in this draft because no corresponding manufacturing process has been qualified. Same-net solder wicking, mask webs, castellations, edge plating and assembly access require additional application-specific checks.

## KiCad integration

The [KiCad 10 custom-rule documentation](https://docs.kicad.org/10.0/en/pcbnew/pcbnew.html#custom_design_rules) defines version 1 syntax. More specific conditions appear later because matching rules are evaluated in reverse order. The file uses `A.Type == 'Via'` separately from `A.Type == 'Pad' && A.isPlated()`. `hole_to_hole` measures edge-to-edge drill separation; `hole_clearance` checks different-net copper from the drilled perimeter. It must not be replaced with a same-net physical clearance rule that would reject the pad surrounding its own plated hole.

For an adopted candidate, place the draft beside the board using the same basename, for example `pcbgolf.kicad_dru`. Recommended `.kicad_pro` values in `board.design_settings.rules`:

```json
{
  "min_clearance": 0.10,
  "min_track_width": 0.10,
  "min_copper_edge_clearance": 0.30,
  "min_hole_clearance": 0.20,
  "min_hole_to_hole": 0.20,
  "min_through_hole_diameter": 0.15,
  "min_via_diameter": 0.25,
  "min_via_annular_width": 0.05
}
```

The `.kicad_dru` is essential: the project-wide annular-ring floor alone cannot express both via and component-pad requirements. Preserve error reporting for annular width, drill size, hole separation, hole clearance, copper clearance, edge clearance and track width. Refill zones before the final DRC. Netclass trace widths are routing defaults; they are not a proof of current capacity.

Reproduce the isolated syntax check and numerical calculations:

```powershell
tools/venv/Scripts/python.exe scripts/manufacturing_rules.py --board candidates/compact-v2-4l/pcbgolf.kicad_pcb
```

## Actual supply constraints

The [PJ-002AH-SMT-TR manufacturer datasheet](https://www.sameskydevices.com/product/resource/pj-002ah-smt-tr.pdf) rates the input jack at **5 A total**. The four channel limits cannot be added to claim a 12.72 A board input rating. The upstream supply, mating plug, jack, reverse-polarity FET, copper and return path all have to support the selected aggregate load. The design currently has no demonstrated aggregate 5 A enforcement; the source must be current-limited or an appropriate board-level protection change must be designed.

For a 28 kΩ current-limit resistor, the [TPS25942/44 datasheet](https://www.ti.com/lit/ds/symlink/tps25944l.pdf) gives about **3.18 A nominal per channel**. Use 3.5 A as a provisional tolerance allowance until the exact resistor/device limits are closed. Its layout guidance calls for power paths capable of at least twice full-load current, so a 7 A copper screen is included below. It also requires short power paths, local bypassing, a controlled signal-ground connection and thermal copper/vias under the exposed pad. A successful router run does not establish these properties.

The [AP62300 datasheet](https://www.diodes.com/datasheet/download/AP62300.pdf) rates the IC for 3 A, but also recommends 2 oz outer copper, ground layers, and thermal vias for its full-load layout. The current **1 oz** draft needs its own thermal validation. The circuit review found that source L1/L2 (MEKK2520T3R3M, alias LSENC2520KKT3R3M) have about 1.8 A saturation and 2.0 A thermal ratings; thus sustained 3 A outputs are **not established**. The 5 V regulator feeds the 3.3 V regulator, so the 5 V load budget must include that conversion load. OBD-C 12 V power bypasses these bucks.

## Width calculations and proposed netclasses

These are screening calculations with **35 µm outer copper, 17.5 µm inner copper, and a 10°C trace temperature-rise target**. The historical IPC-2221 expression used by [KiCad's track-width calculator](https://docs.kicad.org/10.0/en/pcb_calculator/pcb_calculator.html) is:

`I = k × ΔT^0.44 × A^0.725`, with cross-section `A` in mil² and `k = 0.048` outside or `0.024` inside.

`scripts/manufacturing_rules.py` solves for width. This estimate is not an IPC-2152 thermal model: trace length, neighboring copper, copper thickness tolerance, thermal coupling, ambient temperature and pad/plane connections can materially change the result. The selected widths below include a 25% drawn-width increase to cover a possible 20% width reduction. Verify actual finished copper and loading before release. Widths are for continuous trunk sections; short pad escapes and parallel pad fingers need explicit current-sharing and heat-spreading assessment.

| Proposed class / path | Screening current | Calculated outer width | Proposed drawn trunk width |
|---|---:|---:|---:|
| POWER_INPUT_5A: jack power and common +12V trunk | 5.0 A | 2.766 mm | 3.5 mm or wider pour |
| POWER_CHANNEL: normal per-channel current allowance | 3.5 A | 1.691 mm | 2.2 mm normal-current screen |
| POWER_CHANNEL: 2× margin from TI layout guidance | 7.0 A | 4.399 mm | **5.5 mm effective main-path copper** |
| POWER_5V_3A: L2 output to shared 5 V load | 3.0 A | 1.367 mm | 1.8 mm, conditional on inductor/thermal redesign |
| POWER_3V3_3A: L1 output rail trunk | 3.0 A | 1.367 mm | 1.8 mm, conditional on actual rail rating |
| MCU_BRANCH_1A: provisional MCU supply branch budget | 1.0 A | 0.300 mm | 0.4 mm; 1 A is a planning budget, not measured MCU demand |
| SIGNAL: ordinary low-current logic | Application-dependent | Not evaluated as a power path | 0.127 mm default; 0.10 mm fabrication floor |

The local TPS input path also needs the TI current margin. A common input segment carrying the full 5 A has a 10 A margin screen of 7.194 mm finished, or 9.0 mm drawn; use a broad, short plane connection where practical and review the connector/FET bottlenecks. This conservative screen is an indication to engineer the power distribution, not a requirement to route every small power pin with a 9 mm trace.

Avoid long power paths on the default half-ounce inner layers. At 3 A the same simplified inner-layer calculation needs about 7.11 mm; above 5 A it predicts more than 10 mm and leaves the documented width range of the expression. Keep a continuous ground return plane and verify actual local plane neck widths. Give the return path the same current/thermal scrutiny as the supply.

Net assignments to review:

- POWER_INPUT_5A: `Net-(J1-PWR)` and `+12V` (confirm any renamed jack net).
- POWER_CHANNEL: the four `Net-(J5-VBUS-PadA4)` through `Net-(J8-VBUS-PadA4)` output nets; derive exact names from the current candidate.
- POWER_5V_3A and POWER_3V3_3A: `+5V` and `+3V3` trunks. Branches share these net names, so use reviewed geometry/regions rather than blindly applying one enormous width to every decoupling stub.
- GND: a continuous return plane and broad power returns, not a universal 0.127 mm autorouted tree.
- `Net-(U1-SW)` and `Net-(U2-SW)`: short buck switch-node copper according to the reference layout; do not include them in a global wide-plane pour or expand them without EMI review.

## Via planning

Use **0.60 mm pad / 0.30 mm finished drill** as the initial power-via geometry; use 0.45/0.20 mm for ordinary signal vias. The smaller fabrication floor is not a power-via rating. Keep high-current routes on one outer layer when practical to avoid many current-sharing vias and their score penalty.

For a 1.6 mm board, assumed 18 µm barrel copper and 35°C copper temperature, a hollow-cylinder resistance calculation gives approximately:

| Finished drill | Calculated barrel resistance |
|---|---:|
| 0.20 mm | 2.37 mΩ |
| 0.30 mm | 1.62 mΩ |
| 0.40 mm | 1.24 mΩ |

The model uses copper resistivity 1.724×10⁻⁸ Ω·m at 20°C and coefficient 0.00393/°C; it follows the basic cylindrical conductor approach used in [KiCad's via calculator source](https://docs.kicad.org/doxygen/panel__via__size_8cpp_source.html). JLC's 18 µm figure is an average plating figure, **not a verified minimum for this order**. Resistance alone does not establish a permissible temperature rise or reliable current sharing.

Until the via/plane thermal model is validated, a conservative planning cap is **0.5 A per 0.30 mm power via**, with symmetrical placement and wide connections on both ends. That suggests at least 10 vias for a 5 A transition, 6 for a 3 A rail, and 14 for a 7 A channel-margin transition. This is an explicit engineering planning assumption, not a manufacturer ampacity specification. Reducing via counts needs a justified thermal/current-sharing analysis or a larger cross-section; do not silently route a whole power path through one small signal via.

Thermal-via requirements at the regulator/eFuse exposed pads remain separate from this current-sharing count. Unfilled via-in-pad may wick solder; placement, fill/tent process and assembly must be specified. Low score never substitutes for measured load, rail-voltage, temperature-rise and fault-response validation.

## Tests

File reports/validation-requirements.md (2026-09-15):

# PCBGolf validation and submission requirements

Checked against official sources on 2026-09-14. This document describes validation requirements; it is not a claim that the current candidate is ready for fabrication or submission.

## Official acceptance and score

The challenge scores the assembled board's bounding-box volume in mm³, plus 50 per via and 5,000 per enabled copper layer. A compact layout must preserve the original interfaces and functionality, be manufacturable as a bare board by JLCPCB, be physically assembleable, work, and permit compatible mating connectors. A copper outline or board-area estimate alone is insufficient. Source: [official challenge](https://github.com/commaai/PCBGolf).

Submit a ZIP containing the finalized KiCad project and a complete assembly STEP through the [official submission form](https://forms.gle/US88Hg7UR6bBuW3BA). Multiple entries are allowed; reviewers publish competitive results. The prize deadline is October 12, 2026. The [leaderboard](https://comma.ai/leaderboard#pcbgolf_challenge) has no visible PCBGolf score rows in the retrieved page as of this check. Form fields and authentication requirements have not been verified; do not infer submission success from creating the ZIP.

## Fabrication limits to configure

The current [JLCPCB rigid capabilities table](https://jlcpcb.com/capabilities/pcb-capabilities) gives these useful limits for 1 oz copper:

| Feature | Published capability |
|---|---|
| Trace/space, 1–2 layers | 0.10/0.10 mm |
| Trace/space, multilayer | 0.09/0.09 mm |
| Via hole/diameter | 0.15/0.25 mm, added cost; 0.20 mm drill preferred |
| Via drill to another via drill | 0.20 mm |
| Via hole to track/inner copper | 0.20 mm |
| SMD pad to another-net pad | 0.15 mm |
| Routed board edge to copper | 0.20 mm |
| PTH annular ring, 2 layers/multilayer | 0.18/0.15 mm absolute minimum |
| Standard FR4 thickness options | Start at 0.4 mm; verify the selected layer stack |

The small via ring limit does not remove drill-to-copper spacing. Thin boards require compatible finish and sufficient connector stiffness. The same page's FAQ and detailed table disagree about blind/buried vias; use through-vias unless a specific advanced process is confirmed. These are fabrication constraints, not minimum safe widths for power or controlled-impedance signals.

## Engineering review that geometry/DRC cannot replace

- Check 12 V input and each powered OBD-C channel for required current, copper width/temperature rise, connector ratings, protection and regulator stability.
- Verify USB and clock placement/routing against the component reference designs, actual stackup, differential geometry, return paths, stubs and matching requirements.
- Keep capacitors adjacent to their associated supply pins; preserve the analog current-sense loop and switch-mode power loop geometry.
- Check all component models against actual manufacturer package drawings. The model must represent body, leads, shield and every protruding part correctly.
- Test solder access, underside clearances, assembly sequence and physical collision in the complete 3D model, including drill and board-thickness tolerances.
- Provide clearance for all five USB/OBD-C plugs, the barrel plug, the microSD card's insertion/ejection envelope, and finger/tool operation of the push button. Close-packed receptacles can fit while their plugs do not.
- Audit J4 (CAN 2x04): source marks it DNP and has no 3D model. If the intended interface requires a fitted header, obtain the correct header model and include it in the assembly. The source's four mounting positions are also DNP; their removal needs to stay consistent between board and schematic.

## Repeatable local checks

The source project has **five top-level schematic sheets**. KiCad 10.0.6 `pcb drc --schematic-parity` can load only the primary sheet in this project, causing false extra-footprint reports. Exporting just `pcbgolf.kicad_sch` also captures only the power sheet.

`scripts/validate_connectivity.py` exports each top-level sheet to KiCad XML, merges component/pin connectivity, and compares it against the candidate PCB. It checks component presence, value, footprint, DNP state, and electrical peer groups for every numbered pin. Peer groups avoid treating harmless KiCad generated-net renames as rewiring. Reports include hashes to detect changed inputs.

```powershell
tools/venv/Scripts/python.exe scripts/validate_connectivity.py --board candidates/tiny.kicad_pcb --project pcbgolf.kicad_pro --output reports/tiny-connectivity.json
```

`scripts/score_assembly.py` counts top-level via objects and enabled layers by their `.Cu` names (not KiCad numeric IDs), checks outlines/model presence, consumes or runs DRC, and reads final STEP geometry with OpenCascade. It reports axis-aligned bounding-box dimensions and volume, never material volume. A raw arithmetic result is `candidate_score`; `validated_score` stays null when checks fail or evidence is incomplete. Automated success still requires the engineering review above.

```powershell
tools/venv/Scripts/python.exe scripts/score_assembly.py --board candidates/tiny.kicad_pcb --project-root . --step candidates/tiny.step --kicad-cli tools/kicad/bin/kicad-cli.exe --export-step --connectivity-json reports/tiny-connectivity.json --output reports/tiny-score.json
```

The export includes the board and all populated components. Source DNP components are separately listed in the audit and omitted with KiCad's `--no-dnp` flag. A supplied STEP without a fresh controlled export remains provisional because it might omit components. CAD-model fidelity, mating access and collisions still require review. Avoid `--board-only`, `--no-components`, and component filters when creating the submission STEP.

Scoring implementation verified using two separated known solid boxes: their aggregate bounding box measured 12 × 3 × 4 mm = 144 mm³, instead of the 48 mm³ material volume. The same check verified four copper-layer penalties, one via penalty, and invalidation for missing outline/model. A source capacitor model independently measured 2 × 1.25 × 1.25 mm as expected.

## Portable routing installation

Installed entirely under the project:

- `tools/freerouting/freerouting-2.4.1.jar` — [upstream release v2.4.1](https://github.com/freerouting/freerouting/releases/tag/v2.4.1), released September 3, 2026. SHA-256: `251101c3eeac22d7e7dfcf6796603279e5d1000283eb82d8f093780f7afc6aa9`.
- `tools/java/jdk-25.0.4.1+1-jre/` — [official Eclipse Temurin Java 25 archive](https://github.com/adoptium/temurin25-binaries/releases/tag/jdk-25.0.4.1%2B1). ZIP SHA-256: `4c95451cea98556def2c54f7782933f52a26d4a36bd85e1d59f0364464828b07`.
- `tools/freerouting/route.ps1` — wrapper selecting this JRE/JAR, disabling GUI, API server and anonymous analytics, and saving settings/logs under `tools/freerouting/profile`.

Both upstream archive checksums match. Java version and wrapper help invocation pass. No global installation, PATH modification, server or account is needed.

```powershell
& tools/freerouting/route.ps1 -de candidates/tiny.dsn -do candidates/tiny.ses -mp 20 -mt 4
```

Use the production DSN/SES exchange path and import the SES back into the matching placed board. Native KiCad Python provides `ExportSpecctraDSN` / `ImportSpecctraSES`. After import, refill copper zones and run KiCad DRC; router-local clearance checking does not cover every KiCad/JLCPCB rule.

The [upstream CLI documentation](https://github.com/freerouting/freerouting/blob/v2.4.1/docs/command_line_arguments.md) exposes pass limits (`-mp`), optimizer threads (`-mt`), selection/update strategies, and layer direction controls. **Empirical/source corrections for 2.4.1:** `-drc` runs DRC-only and exits, so omit it from a routing invocation. `-mt 0` only sets the optimizer thread count; it does **not** disable the optimizer. Use `--router.optimizer.enabled=false` for a bounded routing-only trial. The documented `--router.via_costs=150` flag is rejected as unknown; the verified path is `--router.scoring.via_costs=150`. These documentation examples were disproven by candidate runs and checked against the pinned source. Try bounded feasibility runs before long optimization. Do not ignore GND/power net classes unless they are deliberately handled separately and later verified connected. The router's internal optimization score is different from the challenge formula. Compare all candidates using the same final assembly scorer.

Actual 2.4.1 settings were subsequently verified against bundled bytecode and a DEBUG DRC-only run: `--router.fanout.enabled=false` disables the fanout phase, and `--router.scoring.via_costs=150` is the accepted nested scoring field. `reports/router-settings-verification.log` explicitly records both as applied CLI settings, taking priority over DSN settings, and confirms analytics are disabled. These can be added to routing comparisons; higher via cost does not guarantee a better final challenge score.

The initial compact-v2-4l candidate STEP measures 45.0 × 42.0000001 × 15.0050001 mm: 28,359.4503 mm³. Four copper layers add 20,000, before via penalties. This is only an unrouted candidate estimate: the report correctly rejects eligibility while 499 connections remain unconnected.

## Final packaging gate

1. Finish complete routing, zone fill, board DRC, combined-sheet connectivity parity and engineering review.
2. Confirm the actual stackup, drilling, copper, assembly and connector-access constraints.
3. Export the complete assembly STEP from the exact board being submitted; inspect its bounds and component inclusion.
4. Include the PCB, project, all five schematics, custom symbol/footprint libraries, library tables and referenced STEP assets in a self-contained project ZIP. Resolve `KIPRJMOD` paths inside that ZIP.
5. Save final score and validation reports with input hashes; inspect the ZIP contents before uploading.
6. Complete the official form and retain the form's confirmation. A submitted entry is distinct from a reviewed leaderboard listing.

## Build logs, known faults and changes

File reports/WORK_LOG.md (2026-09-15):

# PCBGolf engineering log

## Objective
Minimize a valid, manufacturable and usable PCBA score; validate and submit
the complete KiCad project plus assembly STEP through the official form.
No valid score or leaderboard submission has been claimed yet.

## Reference
- Official source commit: `7210bdb5049c5b7fdf4900a34928e2736767292a`
- Source is KiCad 10: 245 footprints, 302 named nets, no board outline,
  no tracks or vias. Initial DRC reports 499 unconnected items.
- Source has five top-level schematic sheets. CLI schematic parity against
  only the power sheet is incomplete and must not be used as a full audit.

## Local tools
- `tools/kicad/bin/kicad-cli.exe` and `tools/kicad/bin/python.exe`: KiCad10.0.6.
  Official installer SHA256 verified:
  `9e24dc47119f7c472128c2f293c5e3f35569274a44c905e60a7514d47c16ce48`.
  Extracted as portable files with official7-Zip26.03 under WSL.
- `tools/venv/Scripts/python.exe`: analytical Python with sexpdata, NumPy,
  SciPy, Shapely, Matplotlib, OCP and OR-Tools.
- FreeRouting2.4.1 and portable Temurin25 are ready in `tools/`.
- Tools stay inside this workspace and are excluded from git.

## Active work
- Main: reproducible board generator, routing integration, native DRC.
- Circuit audit agent: verified schematic/BOM/footprint corrections.
- Placement agent: concrete compact two-sided placement.
- Validation agent: strict assembly scorer, submission requirements,
  portable autorouter and netlist comparison.

## Submission gates
Complete electrical connectivity, manufacturing DRC, exact schematic parity,
power/current/thermal checks, USB routing checks, collision and mating access,
complete assembly STEP, reproducible packaged project and truthful score.

## First compact candidates
- `reports/placement-45x42*.json` and `scripts/build_candidate.py` reproduce
  candidates. Source schematic and library corrections are encoded in
  `reports/circuit-patches.json` and applied to candidate boards automatically.
- V2:239 components, exact combined5-sheet netlist parity passes. Physical
  assembly STEP measures45×42×15.005mm;28,359.45mm³ volume. This is NOT a
  valid entry score: routing is incomplete and source connector needs replacement.
- V3: uses actual courtyards and has zero native pre-routing DRC errors under
  the trial rule set. It excludes111 unused symbol pins from the router only,
  preserving their logical net assignments in the saved KiCad PCB.
- Native KiCad10 SWIG caveat: retain detached footprint wrappers until exit;
  dropping them can invalidate subsequent plugin return types. Builder handles it.
- V2 router trials used inefficient unused-pin fanout and an invalid source
  connector; stopped as superseded. V3 four-layer no-fanout routing is running.
- The originalJ3 signalPTH geometry fails JLCPCB's separate component-hole
  annular ring and hole-spacing requirements. A USB2-compatible surface-mount
  replacement is being verified; current candidates must not be submitted.
- Current-monitor resistor change33k→10k requires3.3× current-conversion
  scale adjustment, explicitly recorded in the circuit report and patch JSON.

## Current working project (V5)
- Root `pcbgolf.kicad_pcb` is now the corrected239-part45×37mm placement,
  matching the five root schematic sheets. It is **not routed**.
- Root `.kicad_pro` and `.kicad_dru` use the tested four-layer JLC draft rules.
- USB4105-GF-A host connector replaces the invalid hybrid signal-hole design;
  its four ground landing pads use the manufacturer's rounded-end shape to
  maintain>=0.22mm clearance to the unchanged locating holes.
- Native pre-route DRC: zero geometric/fabrication errors; **at least499**
  unconnected items remain and254 warnings (mostly inherited silk/text) need
  cleanup. KiCad caps this category at499; see the count-limit report.
- Fresh assembly dimensions45×37×14.23mm, volume23,692.95mm³. Arithmetic
  baseline43,692.95 plus50per eventual via is **not a valid challenge score**.
- V4 plane-routing trial runs in `candidates/compact-v4-planes`; V3 all-signal
  trial runs independently. Candidate imports must be checked with native DRC,
  power-current constraints, USB coupling/skew, and combined schematic parity.

## Claude
Computer Use was stopped by the user with Escape. No further UI input was
sent in that turn. Local analysis and explicitly requested subagents continued.
The installed Claude CLI was subsequently tried for a read-only Fable review;
it returned an expired OAuth session before making any model call. No review
was obtained and no Claude findings are claimed.

## September14 routing and topology work
- Public entry identity is ExplodingCB, supplied by the user; local gh matches.
  No verified contact email is available yet. No submission has been sent.
- `reports/placement-45x37-mating.json` reserves simultaneous compliant cable
  clearance. The original working root remains V5 until the topology changes
  below can be merged as one checked candidate; do not submit its old port row.
- `reports/placement-power-clusters.json` and `candidates/power-base` put all
  four eFuses on the back beneath the ports, moving40 small parts. Placement
  remains45x37mm with239 parts, zero native physical errors and exact parity.
- The USB agent is reversing channel positions to match hub pin order and
  prerouting all six pairs. J8/J7/J6/J5 run left-to-right. Rotation270 preserves
  mechanical envelopes. The first CH1 pair passes native DRC with no missing
  pair connections; all six pairs and ground references remain in progress.
- JLC04161H-3313 four-layer impedance calculation gives90.1581ohm for0.11mm
  traces with0.10mm gap; source details in `usb-impedance-stackup.md`.
- `scripts/preconnect.py` now uses only orthogonal/45-degree copper. Arbitrary
  straight angles triggered FreeRouting trace-normalization oscillations.
- `scripts/route_ground.py` adds shared, collision-checked signal-ground
  transitions without assuming unfilled via-in-pad assembly. The V8 trial has
  89 ground vias, zero native physical errors and436 uncapped missing routes.
- `scripts/prepare_router.py` exports fresh, hash-linked DSNs and removes eight
  false self-overlap reports by preserving the exact same-net copper union.
  Router DRC is not interchangeable with native KiCad manufacturing DRC.
- Old V3/V4/V7 routing trials were stopped as superseded; none produced a
  finished design. V8 four-layer and six-layer three-pass comparisons run in
  `candidates/v8-route-test` and `candidates/v8-sixlayer-test` respectively.
  The six-layer version is a routing-capacity experiment with no validated
  fabrication stackup or impedance claim.
- `reports/mcu-bga100-feasibility.json` uses ST's official pin database to show
  a complete STM32H725VGH6 allocation:82 connected balls,18 NC,10 GPIO changes.
  This 8x8mm0.8pitch package is a separate optimization branch. Schematic,
  firmware, supply scheme and real escape validation are still required.
- Paid4-layer filled/capped POFV is supported by JLC and is being specified
  for thermal pads and unavoidable hub crossovers. Use0.20mm drilled holes on
  1.6mm board;0.15mm drill is not assumed to satisfy the published10:1 ratio.

## Current measured routing results (20:20 local)

- V8 four-layer imported trial: 2,047 track segments,301 vias,199 native
  missing connections. Native physical errors:3 shorts,1 copper clearance,
  16 hole-clearance records and4 solder-mask bridges. This is incomplete.
- V8 six-layer imported trial:2,422 segments,362 vias,167 native missing
  connections. The extra2 layers and61 vias cost13,050 points while closing
  only32 more connections. Continue the smaller MCU/four-layer branch.
- Q1's fixed-wire-polygon router substitute proved unsafe after import:
  FreeRouting treats those polygons as non-obstacle conduction areas. The
  exporter now retains partly overlapping Q1 pads and only deduplicates
  fully contained J3 pads. Old polygon-based DSNs are superseded.
- KiCad10 verified locked tracks/vias export as DSN `type fix`. Critical
  USB and power routes must be locked before general autorouting.
- `analyze_routes.py` now uses layer-qualified via width (avoids a native
  assertion/hang), has a subprocess timeout, and models direct via-to-pad
  contacts. It finds all four manually routed USB port paths; CH2's final
  via balancing, the host pair and MCU pair remain in progress.
- `candidates/power-base/power-critical.kicad_pcb` has143 locked power
  segments and58 locked vias, including16 thermal vias. Native physical DRC
  has zero errors and five-sheet parity passes. Filled-copper connectivity
  confirms input/eFuse/port power paths. Local bulk caps, MCU decoupling and
  feedback placement still require the BGA placement; see power report.
- `candidates/bga100-base` retains239 parts and191 connected net names,
  matches all100 ST package pins, passes five-sheet parity and has zero
  native nonrouting errors. Initial escape routes66 of82 connected balls
  with36 vias;16 balls are blocked by opposite-side components. The power
  and escape agents are coordinating the needed placement changes.
- Local historical panda firmware is checked out read-only for analysis
  in `tools/panda-firmware` at78cf69904c332c599a297fcc2a09c08d10d429d5.
  No firmware port, public repository push, or challenge submission exists.

## September 14, 2026 — owner-requested stop
All three subagents and optimization work stopped to conserve usage. Saved the merged incomplete BGA100 board in work-in-progress and experimental firmware source in firmware/pcbgolf. This is a WIP GitHub checkpoint, not a leaderboard entry. Resume only on owner request.

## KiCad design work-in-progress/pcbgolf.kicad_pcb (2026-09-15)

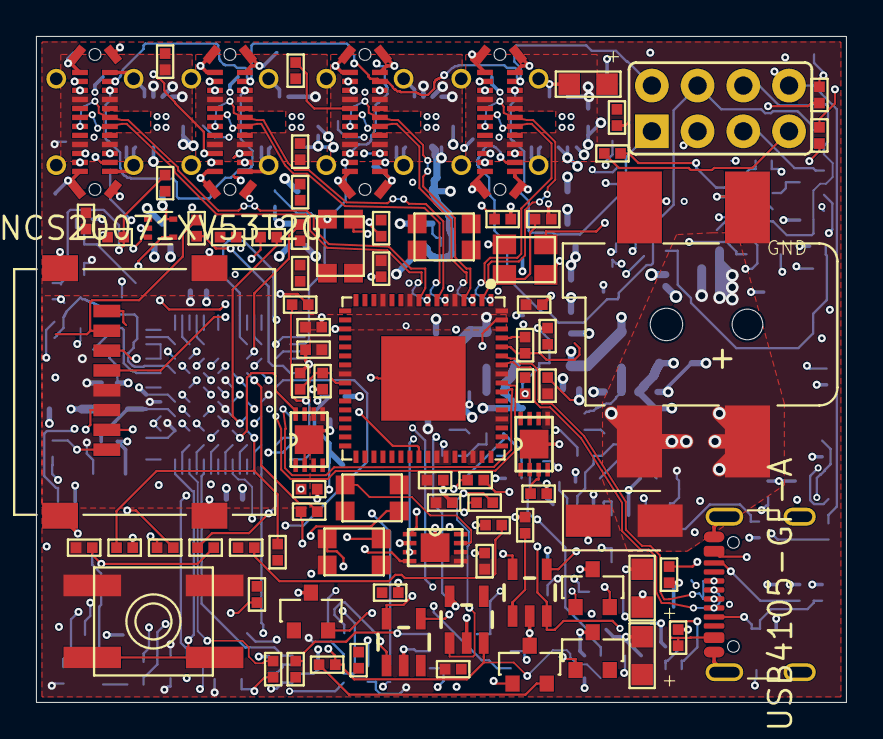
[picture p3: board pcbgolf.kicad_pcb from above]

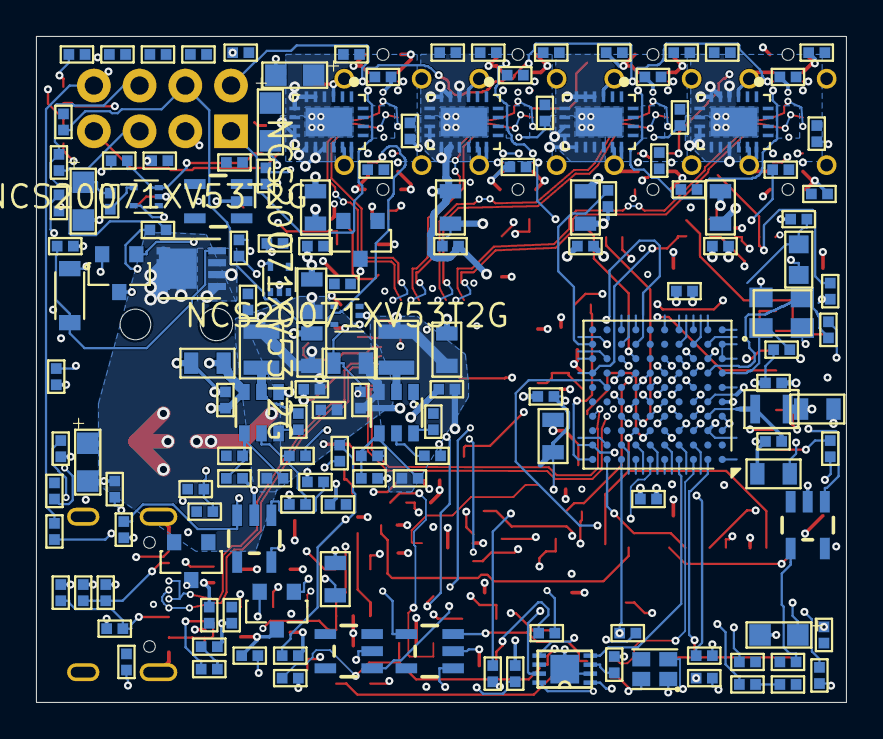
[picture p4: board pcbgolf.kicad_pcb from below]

Board: 4 copper layers, 45.0 x 37.0 mm, 239 parts (154 on the bottom side), 191 nets.

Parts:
C1, C3, C8, C12, C13, C15, C19, C20, C21: 10uF; 0805-C
C2, C4, C5, C7, C9, C11, C16, C18, C22, C23, C24, C26, C27, C30, C31, C35, C36, C38, C39, C40, C41, C42, C43, C44, C45, C46, C47, C48, C49: 100nF; 0402-C
C6, C10: DNP; 0402-C
C14, C17, C28, C32: 12pF; 0402-C
C25: 220pF; 0402-C
C29, C33, C34, C37: 10u; 0402-C
C50, C51, C52, C53: 10u; 0805-C
D1: SMAJ16CA; D_SMA
D2: DIODEDB2W40100L; SOD-123F
J1: DCBARRELSMT; PJ-002AH-SMT-TR
J2: MICRO_SD-0472192001; 0472192001
J3: USB4105-GF-A; USB_C_Receptacle_GCT_USB4105-xx-A_16P_TopMnt_Horizontal
J4: CAN; 2X04
J5, J6, J7, J8: USB-C-FEMALEGCT; USB-C-FEMALE-VERT-GCT
L1, L2: 3u3; L-1008
L3: L-US-L2; 0603-L
L4: 2u2; 0806
L5, L6, L7, L8: ACT1210D_CHOKE; CHOKE-3.2X2.5
LED1: CREE-RGB-CLMVC
LED2: CAN0; CHIPLED
LED3: CAN1; CHIPLED
LED4: CAN2; CHIPLED
LED5: CAN3; CHIPLED
LED6, LED7, LED8, LED9: CH1_PWR; CHIPLED
LED10, LED11, LED12, LED13, LED14, LED15, LED16, LED17: LED-CC-GREEN-RED-AM23ESG; SOT23-3
Q1: SIS427-VI; PP-1212-8
Q2, Q3, Q4, Q5, Q6, Q7, Q8, Q9: NFET-DUAL-COMMON-SOURCE-QS5K2; SOT23-5
R1, R3, R7, R8, R9, R11, R12, R28, R29, R30, R31, R32, R33, R34, R35, R36, R37, R44, R45, R50, R51, R53, R54, R56, R57, R59, R60, R70, R71, R72, R73, R78, R79, R80, R81, R98, R99, R100, R101, R102, R103, R104, R105, R122, R123, R124, R125: 10k; 0402-R
R2, R21, R23, R90, R92, R94, R96, R114, R116, R118, R120: 1k; 0402-R
R4: 31k2; 0402-R
R10: 52k3; 0402-R
R13, R14, R15, R16, R17, R18, R19, R20, R24, R25, R52, R55, R58, R61: 100k; 0402-R
R22, R62, R63, R64, R65: 2k7; 0402-R
R26: 1M; 0402-R
R27: 12k; 0402-R
R38, R39, R40, R41, R42, R43: 0R; 0402-R
R46, R47, R48, R49: 60; 0402-R
R66, R67, R68, R69: 28k; 0402-R
R74, R75, R76, R77: 3k3; 0402-R
R82, R83, R84, R85, R86, R87, R88, R89, R91, R93, R95, R97, R106, R107, R108, R109, R110, R111, R112, R113, R115, R117, R119, R121: 100; 0402-R
SW1: SPST-2-4PIN; EVQ-Q2
U1, U2: AP62300; SOT23-6
U3: STM32H725VGH6; STM32H725VGH6_TFBGA100
U4: USB2517; QFN64-9X9
U5, U6, U7, U8: MCP2542FDT-E/MNY; TDFN8_2X3MC_MCH
U9, U10, U11, U12: NCS20071XV53T2G; SOT-553
U13, U14, U15, U16: TPS25944A; WQFN20
Y1: 25MHz; XTAL-3.2X2.5
Y2: 24MHz; XTAL-3.2X2.5

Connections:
+3V3: C6.2, C7.1, C8.1, C19.1, C20.1, C23.1, C24.1, C26.1, C27.1, C30.2, C31.2, C37.1, C42.1, C43.1, C44.1, C45.1, J2.4 (VDD), L1.2, L3.1, LED1.U1 (COM+), R4.1, R11.1, R28.1, R29.1, R30.1, R33.1, R34.1, R35.1, R36.1, R37.1, SW1.B (S), SW1.B' (S1), U3.C2, U3.D6, U3.E1, U3.E5, U3.E8, U3.F6, U4.5 (VDDA33), U4.10 (VDDA33), U4.13 (CFG_SEL2), U4.24 (VDD33CR), U4.42 (CFG_SEL1), U4.43 (RESET_N), U4.46 (VDD33), U4.52 (VDDA33), U4.57 (VDDA33), U4.64 (VDD33PLL), U5.5 (VIO), U6.5 (VIO), U7.5 (VIO), U8.5 (VIO)
+5V: C1.1, C2.1, C10.2, C11.1, C12.1, C13.1, C38.1, C39.1, C40.1, C41.1, L2.2, R1.1, R10.2, R52.2, R55.2, R58.2, R61.2, U1.3 (IN), U5.3 (VDD), U6.3 (VDD), U7.3 (VDD), U8.3 (VDD)
+12V: C3.1, C5.1, C46.1, C47.1, C48.1, C49.1, C50.1, C51.1, C52.1, C53.1, D2.1 (C), Q1.1 (S), Q1.2 (S), Q1.3 (S), R7.1, U2.3 (IN), U9.5, U10.5, U11.5, U12.5, U13.9 (VIN), U13.10 (VIN), U13.11 (VIN), U13.12 (VIN), U13.13 (VIN), U14.9 (VIN), U14.10 (VIN), U14.11 (VIN), U14.12 (VIN), U14.13 (VIN), U15.9 (VIN), U15.10 (VIN), U15.11 (VIN), U15.12 (VIN), U15.13 (VIN), U16.9 (VIN), U16.10 (VIN), U16.11 (VIN), U16.12 (VIN), U16.13 (VIN)
BTN: R12.2, SW1.A, SW1.A' (P1), U3.A2, U3.A5
CAN0_EN: U3.B5, U5.8 (STBY)
CAN0_H: J4.2, J5.A2 (TX1+), J6.A2 (TX1+), J7.A2 (TX1+), J8.A2 (TX1+), L5.4, R46.2, R50.1
CAN0_L: J4.1, J5.A3 (TX1-), J6.A3 (TX1-), J7.A3 (TX1-), J8.A3 (TX1-), L5.3, R46.1, R51.1
CAN0_RX: U3.A4, U5.4 (RXD)
CAN0_TX: U3.E3, U5.1 (TXD)
CAN1_EN: U3.B6, U6.8 (STBY)
CAN1_H: J4.4, J5.A11 (RX2+), J6.A11 (RX2+), J7.A11 (RX2+), J8.A11 (RX2+), L6.4, R47.2, R53.1
CAN1_L: J4.3, J5.A10 (RX2-), J6.A10 (RX2-), J7.A10 (RX2-), J8.A10 (RX2-), L6.3, R47.1, R54.1
CAN1_RX: U3.A6, U6.4 (RXD)
CAN1_TX: U3.D4, U6.1 (TXD)
CAN2_EN: U3.C6, U7.8 (STBY)
CAN2_H: J4.6, J5.B2 (TX2+), J6.B2 (TX2+), J7.B2 (TX2+), J8.B2 (TX2+), L7.4, R48.2, R56.1
CAN2_L: J4.5, J5.B3 (TX2-), J6.B3 (TX2-), J7.B3 (TX2-), J8.B3 (TX2-), L7.3, R48.1, R57.1
CAN2_RX: U3.H9, U7.4 (RXD)
CAN2_TX: U3.H10, U7.1 (TXD)
CAN3_EN: U3.C5, U8.8 (STBY)
CAN3_H: J4.8, J5.B11 (RX1+), J6.B11 (RX1+), J7.B11 (RX1+), J8.B11 (RX1+), L8.4, R49.2, R59.1
CAN3_L: J4.7, J5.B10 (RX1-), J6.B10 (RX1-), J7.B10 (RX1-), J8.B10 (RX1-), L8.3, R49.1, R60.1
CAN3_RX: U3.K8, U8.4 (RXD)
CAN3_TX: U3.J8, U8.1 (TXD)
CH1_D_N: J5.A7 (D-A), J5.B7 (D-B), U4.1 (USBDN1_DM)
CH1_D_P: J5.A6 (D+A), J5.B6 (D+B), U4.2 (USBDN1_DP)
CH1_IMON: R70.2, U3.H4, U13.19 (IMON)
CH1_PWR_EN: U3.G3, U13.14 (EN)
CH1_SBU1: J5.A8 (SBU1), R19.2, R90.2, R91.2
CH1_SBU1_IGN: Q2.1 (G1), R78.1, R83.2, U3.C7
CH1_SBU1_RELAY: Q2.3 (G2), R82.2, R98.2, U3.B8
CH1_SBU2: J5.B8 (SBU2), R20.2, R114.2, R115.2
CH1_SBU2_IGN: Q6.1 (G1), R102.1, R107.2, U3.A8
CH1_SBU2_RELAY: Q6.3 (G2), R106.2, R122.2, U3.B7
CH2_D_N: J6.A7 (D-A), J6.B7 (D-B), U4.3 (USBDN2_DM)
CH2_D_P: J6.A6 (D+A), J6.B6 (D+B), U4.4 (USBDN2_DP)
CH2_IMON: R71.2, U3.K5, U14.19 (IMON)
CH2_PWR_EN: U3.J2, U14.14 (EN)
CH2_SBU1: J6.A8 (SBU1), R15.2, R92.2, R93.2
CH2_SBU1_IGN: Q3.1 (G1), R79.1, R85.2, U3.D7
CH2_SBU1_RELAY: Q3.3 (G2), R84.2, R99.2, U3.A7
CH2_SBU2: J6.B8 (SBU2), R13.2, R116.2, R117.2
CH2_SBU2_IGN: Q7.1 (G1), R103.1, R109.2, U3.J9
CH2_SBU2_RELAY: Q7.3 (G2), R108.2, R123.2, U3.J10
CH3_D_N: J7.A7 (D-A), J7.B7 (D-B), U4.6 (USBDN3_DM)
CH3_D_P: J7.A6 (D+A), J7.B6 (D+B), U4.7 (USBDN3_DP)
CH3_IMON: R72.2, U3.K4, U15.19 (IMON)
CH3_PWR_EN: U3.K1, U15.14 (EN)
CH3_SBU1: J7.A8 (SBU1), R17.2, R94.2, R95.2
CH3_SBU1_IGN: Q4.1 (G1), R80.1, R87.2, U3.A1
CH3_SBU1_RELAY: Q4.3 (G2), R86.2, R100.2, U3.H7
CH3_SBU2: J7.B8 (SBU2), R18.2, R118.2, R119.2
CH3_SBU2_IGN: Q8.1 (G1), R104.1, R111.2, U3.H8
CH3_SBU2_RELAY: Q8.3 (G2), R110.2, R124.2, U3.H5
CH4_D_N: J8.A7 (D-A), J8.B7 (D-B), U4.8 (USBDN4_DM)
CH4_D_P: J8.A6 (D+A), J8.B6 (D+B), U4.9 (USBDN4_DP)
CH4_IMON: R73.2, U3.J3, U16.19 (IMON)
CH4_PWR_EN: U3.K2, U16.14 (EN)
CH4_SBU1: J8.A8 (SBU1), R16.2, R96.2, R97.2
CH4_SBU1_IGN: Q5.1 (G1), R81.1, R89.2, U3.G7
CH4_SBU1_RELAY: Q5.3 (G2), R88.2, R101.2, U3.G8
CH4_SBU2: J8.B8 (SBU2), R14.2, R120.2, R121.2
CH4_SBU2_IGN: Q9.1 (G1), R105.1, R113.2, U3.B4
CH4_SBU2_RELAY: Q9.3 (G2), R112.2, R125.2, U3.C4
GND: C1.2, C2.2, C3.2, C5.2, C7.2, C8.2, C11.2, C12.2, C13.2, C14.2, C15.2, C16.2, C17.2, C18.2, C19.2, C20.2, C21.2, C22.2, C23.2, C24.2, C25.2, C26.2, C27.2, C28.2, C29.2, C30.1, C31.1, C32.2, C33.2, C34.2, C35.1, C36.1, C37.2, C38.2, C39.2, C40.2, C41.2, C42.2, C43.2, C44.2, C45.2, C46.2, C47.2, C48.2, C49.2, C50.2, C51.2, C52.2, C53.2, D1.1, J1.GND, J1.GNDBREAK, J2.6 (VSS), J2.G1 (GND), J2.G2 (GND), J2.G3 (GND), J2.G4 (GND), J3.A1, J3.A12, J3.B1, J3.B12, J3.SH, J5.A1 (GND), J5.A12 (GND), J5.B1 (GND), J5.B12 (GND), J5.S1 (SHIELDA), J5.S2 (SHIELDA), J5.S3 (SHIELDA), J5.S4 (SHIELDA), J5.S11 (SHIELDB), J5.S12 (SHIELDB), J5.S13 (SHIELDB), J5.S14 (SHIELDB), J6.A1 (GND), J6.A12 (GND), J6.B1 (GND), J6.B12 (GND), J6.S1 (SHIELDA), J6.S2 (SHIELDA), J6.S3 (SHIELDA), J6.S4 (SHIELDA), J6.S11 (SHIELDB), J6.S12 (SHIELDB), J6.S13 (SHIELDB), J6.S14 (SHIELDB), J7.A1 (GND), J7.A12 (GND), J7.B1 (GND), J7.B12 (GND), J7.S1 (SHIELDA), J7.S2 (SHIELDA), J7.S3 (SHIELDA), J7.S4 (SHIELDA), J7.S11 (SHIELDB), J7.S12 (SHIELDB), J7.S13 (SHIELDB), J7.S14 (SHIELDB), J8.A1 (GND), J8.A12 (GND), J8.B1 (GND), J8.B12 (GND), J8.S1 (SHIELDA), J8.S2 (SHIELDA), J8.S3 (SHIELDA), J8.S4 (SHIELDA), J8.S11 (SHIELDB), J8.S12 (SHIELDB), J8.S13 (SHIELDB), J8.S14 (SHIELDB), LED2.C, LED3.C, LED4.C, LED5.C, LED6.C, LED7.C, LED8.C, LED9.C, LED10.3 (C), LED11.3 (C), LED12.3 (C), LED13.3 (C), LED14.3 (C), LED15.3 (C), LED16.3 (C), LED17.3 (C), Q2.2 (S), Q3.2 (S), Q4.2 (S), Q5.2 (S), Q6.2 (S), Q7.2 (S), Q8.2 (S), Q9.2 (S), R2.1, R3.2, R8.2, R9.2, R12.1, R25.1, R27.1, R31.2, R32.2, R44.2, R45.2, R66.1, R67.1, R68.1, R69.1, R70.1, R71.1, R72.1, R73.1, R78.2, R79.2, R80.2, R81.2, R98.1, R99.1, R100.1, R101.1, R102.2, R103.2, R104.2, R105.2, R122.1, R123.1, R124.1, R125.1, U1.1 (GND), U2.1 (GND), U3.C1, U3.D1, U3.D5, U3.E7, U3.F5, U3.H2, U4.19 (TEST), U4.PAD (VSS), U5.2 (VSS), U5.PAD (EPAD), U6.2 (VSS), U6.PAD (EPAD), U7.2 (VSS), U7.PAD (EPAD), U8.2 (VSS), U8.PAD (EPAD), U9.2, U10.2, U11.2, U12.2, U13.3 (PGTH), U13.15 (OVP), U13.16 (GND), U13.PAD (GND), U14.3 (PGTH), U14.15 (OVP), U14.16 (GND), U14.PAD (GND), U15.3 (PGTH), U15.15 (OVP), U15.16 (GND), U15.PAD (GND), U16.3 (PGTH), U16.15 (OVP), U16.16 (GND), U16.PAD (GND), Y1.2 (3), Y1.4 (3), Y2.2 (3), Y2.4 (3)
HUB_SCL: R30.2, U3.K7, U4.41 (SCL)
HUB_SDA: R28.2, U3.J7, U4.40 (SDA)
LED_B: R23.2, U3.A3
LED_G: R22.2, U3.B3
LED_R: R21.2, U3.C3
unnamed: D2.2 (A), Q1.4 (G), R2.2
unnamed: D1.2, J1.PWR1, Q1.5 (D), Q1.6 (D), Q1.7 (D), Q1.8 (D), Q1.9 (D)
unnamed: J2.2 (CD/DAT3), R36.2, R41.2
unnamed: J2.5 (CLK), R43.2
unnamed: J2.3 (CMD), R37.2, R42.2
unnamed: J2.7 (DAT0), R33.2, R38.2
unnamed: J2.8 (DAT1), R34.2, R39.2
unnamed: J2.1 (DAT2), R35.2, R40.2
unnamed: J3.A5, R31.1, R32.1
unnamed: J3.B5, R44.1, R45.1
unnamed: J5.A4 (VBUS), J5.A9 (VBUS), J5.B4 (VBUS), J5.B9 (VBUS), R74.1, U13.4 (VOUT), U13.5 (VOUT), U13.6 (VOUT), U13.7 (VOUT), U13.8 (VOUT)
unnamed: J6.A4 (VBUS), J6.A9 (VBUS), J6.B4 (VBUS), J6.B9 (VBUS), R75.1, U14.4 (VOUT), U14.5 (VOUT), U14.6 (VOUT), U14.7 (VOUT), U14.8 (VOUT)
unnamed: J7.A4 (VBUS), J7.A9 (VBUS), J7.B4 (VBUS), J7.B9 (VBUS), R76.1, U15.4 (VOUT), U15.5 (VOUT), U15.6 (VOUT), U15.7 (VOUT), U15.8 (VOUT)
unnamed: J8.A4 (VBUS), J8.A9 (VBUS), J8.B4 (VBUS), J8.B9 (VBUS), R77.1, U16.4 (VOUT), U16.5 (VOUT), U16.6 (VOUT), U16.7 (VOUT), U16.8 (VOUT)
unnamed: LED1.U4 (B-), R23.1
unnamed: LED1.U3 (G-), R22.1
unnamed: LED1.U2 (R-), R21.1
unnamed: LED2.A, R62.2
unnamed: LED3.A, R63.2
unnamed: LED4.A, R64.2
unnamed: LED5.A, R65.2
unnamed: LED6.A, R74.2
unnamed: LED7.A, R75.2
unnamed: LED8.A, R76.2
unnamed: LED9.A, R77.2
unnamed: LED10.2 (AG), R82.1
unnamed: LED10.1 (AR), R83.1
unnamed: LED11.2 (AG), R84.1
unnamed: LED11.1 (AR), R85.1
unnamed: LED12.2 (AG), R86.1
unnamed: LED12.1 (AR), R87.1
unnamed: LED13.2 (AG), R88.1
unnamed: LED13.1 (AR), R89.1
unnamed: LED14.2 (AG), R106.1
unnamed: LED14.1 (AR), R107.1
unnamed: LED15.2 (AG), R108.1
unnamed: LED15.1 (AR), R109.1
unnamed: LED16.2 (AG), R110.1
unnamed: LED16.1 (AR), R111.1
unnamed: LED17.2 (AG), R112.1
unnamed: LED17.1 (AR), R113.1
unnamed: Q2.5 (D1), R90.1
unnamed: Q2.4 (D2), R91.1
unnamed: Q3.5 (D1), R92.1
unnamed: Q3.4 (D2), R93.1
unnamed: Q4.5 (D1), R94.1
unnamed: Q4.4 (D2), R95.1
unnamed: Q5.5 (D1), R96.1
unnamed: Q5.4 (D2), R97.1
unnamed: Q6.5 (D1), R114.1
unnamed: Q6.4 (D2), R115.1
unnamed: Q7.5 (D1), R116.1
unnamed: Q7.4 (D2), R117.1
unnamed: Q8.5 (D1), R118.1
unnamed: Q8.4 (D2), R119.1
unnamed: Q9.5 (D1), R120.1
unnamed: Q9.4 (D2), R121.1
unnamed: R62.1, U9.4
unnamed: R63.1, U10.4
unnamed: R64.1, U11.4
unnamed: R65.1, U12.4
unnamed: C4.1, U1.6 (BST)
unnamed: R1.2, U1.5 (EN)
unnamed: C6.1, R3.1, R4.2, U1.4 (FB)
unnamed: C4.2, L1.1, U1.2 (SW)
unnamed: C9.1, U2.6 (BST)
unnamed: R7.2, R8.1, U2.5 (EN)
unnamed: C10.1, R9.1, R10.1, U2.4 (FB)
unnamed: C9.2, L2.1, U2.2 (SW)
unnamed: R17.1, U3.F3
unnamed: R18.1, U3.F1
unnamed: R19.1, U3.F4
unnamed: R20.1, U3.G4
unnamed: R11.2, U3.D3
unnamed: R13.1, U3.H3
unnamed: R14.1, U3.G5
unnamed: R15.1, U3.K3
unnamed: R16.1, U3.J4
unnamed: C14.1, U3.G1, Y1.1
unnamed: C17.1, U3.G2, Y1.3 (2)
unnamed: R27.2, U4.63 (RBIAS)
unnamed: R29.2, U4.45 (SUSP_IND)
unnamed: R24.1, R25.2, U4.44 (VBUS_DET)
unnamed: C33.1, C35.2, U4.25 (VDD18)
unnamed: C34.1, C36.2, U4.62 (VDD18PLL)
unnamed: C28.1, R26.2, U4.61 (XTAL1), Y2.1
unnamed: C32.1, R26.1, U4.60 (XTAL2), Y2.3 (2)
unnamed: L5.1, U5.7 (CANH)
unnamed: L5.2, U5.6 (CANL)
unnamed: L6.1, U6.7 (CANH)
unnamed: L6.2, U6.6 (CANL)
unnamed: L7.1, U7.7 (CANH)
unnamed: L7.2, U7.6 (CANL)
unnamed: L8.1, U8.7 (CANH)
unnamed: L8.2, U8.6 (CANL)
unnamed: R50.2, U9.1
unnamed: R51.2, R52.1, U9.3
unnamed: R53.2, U10.1
unnamed: R54.2, R55.1, U10.3
unnamed: R56.2, U11.1
unnamed: R57.2, R58.1, U11.3
unnamed: R59.2, U12.1
unnamed: R60.2, R61.1, U12.3
unnamed: R66.2, U13.17 (ILIM)
unnamed: R67.2, U14.17 (ILIM)
unnamed: R68.2, U15.17 (ILIM)
unnamed: R69.2, U16.17 (ILIM)
SD_CLK: R43.1, U3.A10
SD_CMD: R42.1, U3.A9
SD_D0: R38.1, U3.G10
SD_D1: R39.1, U3.F9
SD_D2: R40.1, U3.B10
SD_D3: R41.1, U3.B9
STM_D_N: U3.D10, U4.55 (USBDN7_DM)
STM_D_P: U3.D9, U4.56 (USBDN7_DP)
USB_D_N: J3.A7, J3.B7, U4.58 (USBUP_DM)
USB_D_P: J3.A6, J3.B6, U4.59 (USBUP_DP)
VBUS: C29.1, J3.A4, J3.A9, J3.B4, J3.B9, R24.2
VDDA: C22.1, L3.2, U3.H1, U3.J1
VDDLDO: C15.1, C16.1, C18.1, C21.1, L4.1, U3.D8, U3.E2, U3.E6, U3.F7, U3.G6
VLXSMPS: C25.1, L4.2, U3.D2

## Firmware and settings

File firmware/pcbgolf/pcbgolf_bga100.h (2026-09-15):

#pragma once

// PCBGolf STM32H725VGH6, four physical ports. See firmware/pcbgolf/pinmap.json.
// Deliberately distinct from Jungle v2 so a stock Jungle updater rejects it.
#define HW_TYPE_PCBGOLF_BGA100 0x80U
#define PCBGOLF_PORT_COUNT 4U
#define PCBGOLF_PORT_MASK 0x0FU
#define PCBGOLF_ADC(a, c) {.adc = (a), .channel = (c), .sample_time = SAMPLETIME_810_CYCLES, .oversampling = OVERSAMPLING_1}

uint8_t harness_orientation = HARNESS_ORIENTATION_NONE;
uint8_t can_mode = CAN_MODE_NORMAL;
uint8_t ignition = 0U;
uint8_t panda_power_bitmask = 0U;

gpio_t power_pins[] = {{GPIOA, 0}, {GPIOA, 1}, {GPIOA, 4}, {GPIOA, 5}};
gpio_t sbu1_ignition_pins[] = {{GPIOD, 0}, {GPIOD, 5}, {GPIOE, 6}, {GPIOD, 14}};
gpio_t sbu1_relay_pins[] = {{GPIOD, 1}, {GPIOD, 6}, {GPIOD, 11}, {GPIOD, 15}};
gpio_t sbu2_ignition_pins[] = {{GPIOD, 3}, {GPIOD, 8}, {GPIOD, 9}, {GPIOE, 0}};
gpio_t sbu2_relay_pins[] = {{GPIOD, 4}, {GPIOD, 10}, {GPIOE, 7}, {GPIOE, 1}};
gpio_t can_enable_pins[] = {{GPIOB, 7}, {GPIOB, 3}, {GPIOD, 7}, {GPIOB, 4}};

const adc_signal_t imon_channels[] = {
  PCBGOLF_ADC(ADC1, 4), PCBGOLF_ADC(ADC1, 5),
  PCBGOLF_ADC(ADC1, 9), PCBGOLF_ADC(ADC1, 3),
};
const adc_signal_t sbu1_channels[] = {
  PCBGOLF_ADC(ADC3, 0), PCBGOLF_ADC(ADC1, 7),
  PCBGOLF_ADC(ADC3, 10), PCBGOLF_ADC(ADC1, 8),
};
const adc_signal_t sbu2_channels[] = {
  PCBGOLF_ADC(ADC3, 1), PCBGOLF_ADC(ADC1, 14),
  PCBGOLF_ADC(ADC3, 11), PCBGOLF_ADC(ADC1, 15),
};

void pcbgolf_set_harness_orientation(uint8_t orientation) {
  if (orientation <= HARNESS_ORIENTATION_2) {
    // Break before make, including changes between the two orientations.
    gpio_set_all_output(sbu1_ignition_pins, PCBGOLF_PORT_COUNT, false);
    gpio_set_all_output(sbu2_ignition_pins, PCBGOLF_PORT_COUNT, false);
    gpio_set_all_output(sbu1_relay_pins, PCBGOLF_PORT_COUNT, false);
    gpio_set_all_output(sbu2_relay_pins, PCBGOLF_PORT_COUNT, false);
    if (orientation == HARNESS_ORIENTATION_1) {
      gpio_set_all_output(sbu1_relay_pins, PCBGOLF_PORT_COUNT, true);
      gpio_set_bitmask(sbu2_ignition_pins, PCBGOLF_PORT_COUNT, ignition);
    } else if (orientation == HARNESS_ORIENTATION_2) {
      gpio_set_all_output(sbu2_relay_pins, PCBGOLF_PORT_COUNT, true);
      gpio_set_bitmask(sbu1_ignition_pins, PCBGOLF_PORT_COUNT, ignition);
    } else {
      // NONE leaves all four switch groups off.
    }
    harness_orientation = orientation;
  }
}

void pcbgolf_enable_can_transceiver(uint8_t transceiver, bool enabled) {
  if ((transceiver >= 1U) && (transceiver <= 4U)) {
    gpio_t pin = can_enable_pins[transceiver - 1U];
    set_gpio_output(pin.bank, pin.pin, !enabled); // STBY is active high
  }
}

void pcbgolf_set_can_mode(uint8_t mode) {
  if ((mode != CAN_MODE_NORMAL) && (mode != CAN_MODE_OBD_CAN2)) {
    return;
  }
  pcbgolf_enable_can_transceiver(2U, false);
  pcbgolf_enable_can_transceiver(4U, false);
  const uint8_t pins[] = {5U, 6U, 12U, 13U};
  for (uint8_t i = 0U; i < 4U; i++) {
    set_gpio_pullup(GPIOB, pins[i], PULL_NONE);
    set_gpio_mode(GPIOB, pins[i], MODE_ANALOG);
  }
  uint8_t first = (mode == CAN_MODE_NORMAL) ? 5U : 12U;
  set_gpio_alternate(GPIOB, first, GPIO_AF9_FDCAN2);
  set_gpio_alternate(GPIOB, first + 1U, GPIO_AF9_FDCAN2);
  can_mode = mode;
  pcbgolf_enable_can_transceiver((mode == CAN_MODE_NORMAL) ? 2U : 4U, true);
}

void pcbgolf_set_panda_power(bool enable) {
  panda_power = enable;
  panda_power_bitmask = enable ? PCBGOLF_PORT_MASK : 0U;
  gpio_set_all_output(power_pins, PCBGOLF_PORT_COUNT, enable);
}

void pcbgolf_set_panda_individual_power(uint8_t port_num, bool enable) {
  if ((port_num >= 1U) && (port_num <= PCBGOLF_PORT_COUNT)) {
    uint8_t bit = 1U << (port_num - 1U);
    panda_power_bitmask = (panda_power_bitmask & ~bit) | (enable ? bit : 0U);
    panda_power = (panda_power_bitmask != 0U);
    gpio_set_bitmask(power_pins, PCBGOLF_PORT_COUNT, panda_power_bitmask);
  }
}

bool pcbgolf_get_button(void) {
  return get_gpio_input(GPIOE, 5); // PE5, external 10k pulldown, shared BOOT0
}

void pcbgolf_set_ignition(bool enable) {
  ignition = enable ? PCBGOLF_PORT_MASK : 0U;
  pcbgolf_set_harness_orientation(harness_orientation);
}

void pcbgolf_set_individual_ignition(uint8_t bitmask) {
  ignition = bitmask & PCBGOLF_PORT_MASK;
  pcbgolf_set_harness_orientation(harness_orientation);
}

float pcbgolf_get_channel_power(uint8_t channel) {
  // Retain the six-slot Jungle health wire layout: absent channels return zero.
  if ((channel < 1U) || (channel > PCBGOLF_PORT_COUNT)) {
    return 0.0f;
  }
  uint16_t millivolts = adc_get_mV(&imon_channels[channel - 1U]);
  // TPS25944 nominal 52.3 uA/A * R70..R73 10k = 523 mV/A.
  // No per-board offset/gain calibration yet; power assumes nominal 12 V input.
  return ((float)millivolts / 523.0f) * 12.0f;
}

uint16_t pcbgolf_get_sbu_mV(uint8_t channel, uint8_t sbu) {
  if ((channel < 1U) || (channel > PCBGOLF_PORT_COUNT)) {
    return 0U;
  }
  if (sbu == SBU1) {
    return adc_get_mV(&sbu1_channels[channel - 1U]);
  }
  if (sbu == SBU2) {
    return adc_get_mV(&sbu2_channels[channel - 1U]);
  }
  return 0U;
}

void pcbgolf_enable_header_pin(uint8_t pin_num, bool enabled) {
  // PCBGolf has no Jungle GPIO header. Never drive unrelated MCU balls.
  UNUSED(pin_num);
  UNUSED(enabled);
}

void pcbgolf_init(void) {
  gpio_usb_init();
  for (uint8_t i = 1U; i <= 4U; i++) {
    pcbgolf_enable_can_transceiver(i, false);
  }
  set_gpio_pullup(GPIOB, 8, PULL_NONE);
  set_gpio_pullup(GPIOB, 9, PULL_NONE);
  set_gpio_alternate(GPIOB, 8, GPIO_AF9_FDCAN1); // CAN0_RX
  set_gpio_alternate(GPIOB, 9, GPIO_AF9_FDCAN1); // CAN0_TX
  set_gpio_pullup(GPIOD, 12, PULL_NONE);
  set_gpio_pullup(GPIOD, 13, PULL_NONE);
  set_gpio_alternate(GPIOD, 12, GPIO_AF5_FDCAN3); // CAN2_RX
  set_gpio_alternate(GPIOD, 13, GPIO_AF5_FDCAN3); // CAN2_TX
  pcbgolf_set_can_mode(CAN_MODE_NORMAL);
  pcbgolf_enable_can_transceiver(1U, true);
  pcbgolf_enable_can_transceiver(3U, true);
  pcbgolf_set_harness_orientation(HARNESS_ORIENTATION_NONE);
  pcbgolf_set_panda_power(true); // preserve Jungle startup behavior
  set_gpio_mode(GPIOE, 5, MODE_INPUT);
  set_gpio_pullup(GPIOE, 5, PULL_NONE);

  adc_init(ADC1);
  adc_init(ADC3);
  // Direct PC2_C/PC3_C inputs: isolate the digital-pad analog switches.
  register_set_bits(&SYSCFG->PMCR, SYSCFG_PMCR_PC2SO | SYSCFG_PMCR_PC3SO);
  gpio_t analog_pins[] = {
    {GPIOC, 4}, {GPIOB, 1}, {GPIOB, 0}, {GPIOA, 6}, // IMON
    {GPIOC, 2}, {GPIOC, 3}, {GPIOA, 7}, {GPIOA, 2}, // SBU1/2 CH1/2
    {GPIOC, 0}, {GPIOC, 1}, {GPIOC, 5}, {GPIOA, 3}, // SBU1/2 CH3/4
  };
  for (uint8_t i = 0U; i < sizeof(analog_pins) / sizeof(gpio_t); i++) {
    set_gpio_pullup(analog_pins[i].bank, analog_pins[i].pin, PULL_NONE);
    set_gpio_mode(analog_pins[i].bank, analog_pins[i].pin, MODE_ANALOG);
  }
}
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

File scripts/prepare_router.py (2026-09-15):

"""Export fresh DSN, deduplicating only contained same-net SMD lands.

The native PCB is never saved. Partly overlapping pads remain pads: FreeRouting
imports wire polygons as non-obstacle conduction areas, even with type=fix, so
such polygons cannot safely stand in for physical SMD copper. Native DRC remains
authoritative and all physical copper/hole geometry remains.
"""
import argparse
import collections
import copy
import hashlib
import json
import re
from pathlib import Path
import subprocess
import sys


def digest(path): return hashlib.sha256(path.read_bytes()).hexdigest()


def native_export(board_path,dsn_path,geometry_path):
    import pcbnew
    board=pcbnew.LoadBoard(str(board_path));pads=[];nc=0;tracks=[]
    for fp in board.GetFootprints():
        for pad in fp.Pads():
            if pad.GetNetname().startswith('unconnected-'):
                pad.SetNetCode(0);nc+=1
            layers=list(pad.GetLayerSet().CuStack())
            if pad.GetAttribute()!=pcbnew.PAD_ATTRIB_SMD or len(layers)!=1 or not pad.GetNetCode():continue
            poly=pcbnew.SHAPE_POLY_SET()
            pad.TransformShapeToPolygon(poly,layers[0],0,1000,pcbnew.ERROR_OUTSIDE)
            if poly.OutlineCount()!=1:continue
            coords=[[poly.Outline(0).CPoint(i).x/1000,-poly.Outline(0).CPoint(i).y/1000]
                    for i in range(poly.Outline(0).PointCount())]
            pads.append(dict(reference=fp.GetReference(),pin=pad.GetNumber(),net=pad.GetNetname(),
                             layer=board.GetLayerName(layers[0]),polygon_um=coords,
                             rectangular=pad.GetShape()==pcbnew.PAD_SHAPE_RECT,
                             uuid=pad.m_Uuid.AsString()))
    for item in board.GetTracks():
        if isinstance(item,pcbnew.PCB_TRACK) and not isinstance(item,(pcbnew.PCB_VIA,pcbnew.PCB_ARC)):
            a,b=item.GetStart(),item.GetEnd();dx=abs(a.x-b.x);dy=abs(a.y-b.y)
            if min(dx,dy)>2 and abs(dx-dy)>2:tracks.append(item.m_Uuid.AsString())
    if not pcbnew.ExportSpecctraDSN(board,str(dsn_path)):raise RuntimeError('Native DSN export failed')
    protected=[]
    def chain_um(outline):
        return [[outline.CPoint(i).x/1000,-outline.CPoint(i).y/1000] for i in range(outline.PointCount())]
    for z in board.Zones():
        if not z.GetIsRuleArea() or not z.GetDoNotAllowTracks():continue
        poly=z.Outline()
        for layer in z.GetLayerSet().CuStack():
            for i in range(poly.OutlineCount()):
                protected.append(dict(layer=board.GetLayerName(layer),shell=chain_um(poly.COutline(i)),
                    holes=[chain_um(poly.CHole(i,j)) for j in range(poly.HoleCount(i))]))
    geometry_path.write_text(json.dumps(dict(pads=pads,nc_pads_cleared=nc,non_octilinear_tracks=tracks,
        protected_reference_regions=protected)),encoding='utf-8')


def children(node,key):return [r for r in node if isinstance(r,list) and r and str(r[0])==key]
def child(node,key):return next(iter(children(node,key)),None)


def parse_dsn(text):
    """DSN identifiers may contain [], which sexpdata treats as delimiters."""
    import sexpdata as sx
    text=text.replace('(string_quote ")','(string_quote QUOTE)')
    stack=[];root=None
    for token in re.findall(r'"(?:\\.|[^"\\])*"|[()]|[^\s()]+',text):
        if token=='(':
            row=[]
            if stack:stack[-1].append(row)
            else:root=row
            stack.append(row)
        elif token==')':stack.pop()
        elif token.startswith('"'):
            stack[-1].append(token[1:-1].replace('\\"','"').replace('\\\\','\\'))
        elif re.fullmatch(r'[+-]?\d+',token):stack[-1].append(int(token))
        elif re.fullmatch(r'[+-]?(?:\d+\.\d*|\.\d+)(?:[eE][+-]?\d+)?',token):stack[-1].append(float(token))
        else:stack[-1].append(sx.Symbol(token))
    if stack:raise ValueError('Unbalanced DSN')
    return root


def dump_dsn(node):
    import sexpdata as sx
    if isinstance(node,list):return '('+' '.join(dump_dsn(item) for item in node)+')'
    if isinstance(node,sx.Symbol):return str(node)
    if isinstance(node,str):return json.dumps(node,ensure_ascii=False)
    return str(node)


def sanitize(raw,geometry,allow_filled_via_in_pad=False,signal_via_mm=.4,route_width_mm=None):
    import sexpdata as sx
    from shapely.geometry import Polygon
    from shapely.ops import unary_union
    S=sx.Symbol
    # Specctra's quote declaration is not a conventional quoted S-expression.
    tree=parse_dsn(raw)
    structure=child(tree,'structure')
    for region in geometry.get('protected_reference_regions',[]):
        def polygon(points):return [S('polygon'),region['layer'],0]+[v for xy in points for v in xy]
        structure.append([S('keepout'),polygon(region['shell'])]+[
            [S('window'),polygon(h)] for h in region['holes']])
    library=child(tree,'library');network=child(tree,'network');placement=child(tree,'placement')
    if route_width_mm is not None:
        # Router search width only. Existing critical copper is preserved;
        # power ampacity is a separate acceptance check.
        for owner in [structure]+children(network,'class'):
            rule=child(owner,'rule')
            if rule is not None:
                width=child(rule,'width')
                if width is not None:width[1]=round(route_width_mm*1000)
    if allow_filled_via_in_pad:
        control=child(structure,'control')
        if control is None:control=[S('control')];structure.append(control)
        setting=child(control,'via_at_smd')
        if setting is None:control.append([S('via_at_smd'),S('on')])
        else:setting[1]=S('on')
        for stack in children(library,'padstack'):
            if str(stack[1]).startswith('Via'):
                attach=child(stack,'attach')
                if attach is not None:attach[1]=S('on')
        via_suffix='300:150' if signal_via_mm==.3 else '400:200'
        compact_vias=[str(stack[1]) for stack in children(library,'padstack')
                      if re.fullmatch(r'Via\[0-\d+\]_'+via_suffix+'_um',str(stack[1]))]
        if len(compact_vias)!=1:raise ValueError('Expected one existing '+via_suffix+' through-via padstack')
        for netclass in children(network,'class'):
            circuit=child(netclass,'circuit')
            if circuit is not None:
                use=child(circuit,'use_via')
                if use is not None:use[:]=[S('use_via'),compact_vias[0]]
        # A through-via drill must clear foreign PTH copper by .30 mm.
        # .20 mm copper spacing plus >=.10 mm via ring satisfies that rule.
        rule=child(structure,'rule')
        rule.append([S('clearance'),225 if signal_via_mm==.3 else 200,[S('type'),S('via_pin')]])
    wiring=child(tree,'wiring')
    if wiring is None:wiring=[S('wiring')];tree.append(wiring)
    images={str(row[1]):row for row in children(library,'image')}
    instance={str(p[1]):(comp,p) for comp in children(placement,'component') for p in children(comp,'place')}
    netpins={str(pin):str(net[1]) for net in children(network,'net') for pins in children(net,'pins') for pin in pins[1:]}
    groups=collections.defaultdict(list)
    for pad in geometry['pads']:groups[(pad['reference'],pad['net'],pad['layer'])].append(pad)
    removed=collections.defaultdict(set);events=[]
    for (ref,net,layer),pads in groups.items():
        polys=[Polygon(p['polygon_um']) for p in pads]
        used=set()
        for i in sorted(range(len(pads)),key=lambda i:polys[i].area,reverse=True):
            if i in used:continue
            indices={i};pending=[i]
            while pending:
                a=pending.pop()
                for j,p in enumerate(polys):
                    if j not in indices and j not in used and polys[a].intersection(p).area>1e-4:
                        indices.add(j);pending.append(j)
            if len(indices)<2:continue
            originals=[pads[j] for j in indices]
            if len({p['pin'] for p in originals})!=len(originals):
                events.append(dict(reference=ref,status='skipped_duplicate_pin_numbers'));continue
            if any(netpins.get(ref+'-'+p['pin'])!=net for p in originals):
                raise ValueError(f'Native/DSN pin net mismatch for {ref}')
            anchor=i;representations=[polys[anchor]];conversions=[]
            for j in sorted(indices-{anchor}):
                if polys[anchor].covers(polys[j]):
                    conversions.append((j,'contained_identical_or_smaller'))
                else:
                    events.append(dict(reference=ref,net=net,status='retained_partial_overlap',
                                       reason='Wire polygons are not routing obstacles in FreeRouting.'))
                    used.update(indices)
                    conversions=[];break
            if not conversions:continue
            before=unary_union([polys[j] for j in indices]);after=unary_union(representations)
            delta=before.symmetric_difference(after).area
            if delta>1e-5:raise ValueError(f'Copper union changed for {ref}: {delta} square micrometres')
            for j,kind in conversions:
                removed[ref].add(pads[j]['pin'])
            events.append(dict(reference=ref,net=net,layer=layer,anchor_pin=pads[anchor]['pin'],
                               removed_pins=[pads[j]['pin'] for j,_ in conversions],
                               copper_union_symmetric_difference_um2=delta,status='sanitized'))
            used.update(indices)
    for ref,pins in removed.items():
        comp,place=instance[ref];image=copy.deepcopy(images[str(comp[1])]);newname=str(comp[1])+'__router_'+ref
        image[1]=newname
        def pin_number(row):
            atoms=[x for x in row[1:] if not isinstance(x,list)]
            return str(atoms[1])
        image[:]=[r for r in image if not (isinstance(r,list) and r and str(r[0])=='pin' and pin_number(r) in pins)]
        library.append(image);comp.remove(place)
        placement.append([S('component'),newname,place])
        for net in children(network,'net'):
            for pinrow in children(net,'pins'):
                pinrow[:]=[pinrow[0]]+[pin for pin in pinrow[1:] if str(pin) not in {ref+'-'+p for p in pins}]
    placement[:]=[r for r in placement if not (isinstance(r,list) and r and str(r[0])=='component' and not children(r,'place'))]
    text=dump_dsn(tree).replace('(string_quote QUOTE)','(string_quote ")')+'\n'
    return text,events


def main():
    if '--native-export' in sys.argv:
        native_export(*map(Path,sys.argv[-3:]));return 0
    ap=argparse.ArgumentParser(description=__doc__)
    ap.add_argument('--board',type=Path,required=True)
    ap.add_argument('--output',type=Path,required=True)
    ap.add_argument('--kicad-python',type=Path,default=Path('tools/kicad/bin/python.exe'))
    ap.add_argument('--kicad-cli',type=Path,default=Path('tools/kicad/bin/kicad-cli.exe'))
    ap.add_argument('--allow-filled-via-in-pad',action='store_true',help='Require filled and capped processing for every new via overlapping an SMD land')
    ap.add_argument('--routing-via-mm',type=float,choices=(.3,.4),default=.4,
                    help='Through-via diameter; .30/.15mm requires the corresponding padstack in the native source')
    ap.add_argument('--route-width-mm',type=float,choices=(.1,.127),
                    help='Optional router search width; power current capacity requires separate review')
    args=ap.parse_args();board=args.board.resolve();out=args.output.resolve();out.parent.mkdir(parents=True,exist_ok=True)
    before=digest(board);raw=out.with_suffix('.raw.dsn');geo=out.with_suffix('.geometry.json');drc=out.with_suffix('.native-drc.json')
    run=subprocess.run([str(args.kicad_cli.resolve()),'pcb','drc','--format','json','--severity-all','--all-track-errors',
                        '--refill-zones','--output',str(drc),str(board)],capture_output=True,text=True,encoding='utf-8',errors='replace')
    if run.returncode not in (0,5):raise RuntimeError('Native DRC failed: '+run.stdout+run.stderr)
    data=json.loads(drc.read_text(encoding='utf-8-sig'))
    errors=[v for v in data['violations'] if v.get('severity')=='error']
    if errors:raise RuntimeError('Native physical DRC errors must be fixed before preparing router input: '+str(collections.Counter(v['type'] for v in errors)))
    subprocess.run([str(args.kicad_python.resolve()),str(Path(__file__).resolve()),'--native-export',str(board),str(raw),str(geo)],check=True)
    geometry=json.loads(geo.read_text());text,events=sanitize(raw.read_text(encoding='utf-8'),geometry,args.allow_filled_via_in_pad,args.routing_via_mm,args.route_width_mm)
    if digest(board)!=before:raise RuntimeError('Source board changed during export; discard and rerun')
    out.write_text(text,encoding='utf-8')
    report=dict(source_board=str(board),source_sha256=before,source_board_unchanged=True,dsn=str(out),dsn_sha256=digest(out),
                filled_capped_via_in_pad_enabled=args.allow_filled_via_in_pad,
                routing_via_mm=[args.routing_via_mm,.15 if args.routing_via_mm==.3 else .2] if args.allow_filled_via_in_pad else None,
                router_search_width_mm=args.route_width_mm,
                native_physical_errors=0,native_drc_unconnected_reported=len(data['unconnected_items']),
                native_drc_unconnected_count_may_be_capped=len(data['unconnected_items'])>=499,
                nc_pads_cleared_in_router_only=geometry['nc_pads_cleared'],non_octilinear_tracks=geometry['non_octilinear_tracks'],
                edits=events,limitations=['All source PCB pads, geometry and custom DRC rules are retained in the native board.',
                  'Router DSN does not express all native hole, netclass and manufacturing constraints; native post-import DRC is required.',
                  'Partly overlapping same-net pads remain original DSN pads; known router self-overlap reports are not native clearance errors.',
                  'Import SES only into the source board matching source_sha256; native schematic/pad connectivity remains authoritative.'])
    out.with_suffix('.preflight.json').write_text(json.dumps(report,indent=2)+'\n',encoding='utf-8')
    print(json.dumps(report,indent=2));return 0


if __name__=='__main__':raise SystemExit(main())

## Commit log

2026-09-14 Build 45x37 mm PCBGolf placement and validation pipeline
    [pcbgolf.kicad_pcb, pcbgolf.kicad_sch, pcbgolf_3.kicad_sch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]
2026-09-15 Add BGA100 feasibility and checked routing pipeline
    [TFBGA-100_8x8mm_Layout10x10_P0.8mm.step]
2026-09-15 Route and verify shared CAN connector buses in isolated trial
2026-09-15 Save incomplete BGA100 board and firmware checkpoint
    [pcbgolf.kicad_pcb, pcbgolf.kicad_sch, pcbgolf_2.kicad_sch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]
2026-09-15 Advance solo completion to a checked 220-connection WIP
    [assembly.step, pcbgolf.kicad_pcb]
2026-09-15 Hand off latest four-layer PCB, routing artifacts and completion plan
    [pcbgolf.kicad_pcb, pcbgolf.kicad_sch, pcbgolf_2.kicad_sch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]
